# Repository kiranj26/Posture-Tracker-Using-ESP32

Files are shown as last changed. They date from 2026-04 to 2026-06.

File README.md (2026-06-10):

# Posture Tracker V2 — Product Grade Wearable

> **Branch:** `release/v2-product`  
> **Status:** In development  
> **V1 (MVP breadboard):** See [main branch](../../tree/main)

A product-grade evolution of the ESP32 posture tracker. V2 moves from a breadboard
prototype to a wearable device — custom PCB, LiPo battery, haptic motor, and a compact
shoulder-clip form factor small enough to wear all day.

**Hardware:** ESP32-S3-MINI-1 · MPU-6050 · DRV2605L + LRA · MAX98357A · 20mm speaker · 350mAh LiPo  
**Stack:** ESP-IDF 5.5.0 · PlatformIO · C only (no Arduino, no C++)  
**Target size:** 45×35×16mm (PCB + battery + clip)

---

## What's New in V2

| Feature | V1 | V2 |
|---|---|---|
| Alerts | Audio only | Haptic (early) + Audio (escalation) |
| MCU | ESP32 Dev Kit breakout | ESP32-S3-MINI-1 stamp module (built-in PCB antenna) |
| Power | USB only | 350mAh LiPo — 12–15 hr battery life |
| PCB | Breadboard + breakouts | Custom 2-layer PCB, all ICs direct |
| Speaker | 3W 4Ω (50mm, large) | 0.5W 8Ω (20mm, compact) |
| USB | Micro-USB | USB-C with proper CC resistors |
| Buttons | None | 2 buttons — recalibrate + snooze |
| Form factor | ~120×80mm breadboard | 45×35×16mm shoulder clip |

---

## Alert UX — Layered Haptic + Audio

The key design principle: **haptics for early alerts, audio only for escalation.**

| Time / State | Haptic | Audio |
|---|---|---|
| 10° for 3s — WARNING entry | Single tap | Silent |
| WARNING sustained | Double tap | Silent |
| 20° for 5s — BAD entry | Strong double tap | Double beep |
| BAD +8s | Triple pulse | Double beep |
| BAD +16s | Triple pulse | Double beep |
| BAD +24s onwards | Triple pulse | "Sit up straight" — repeats every 8s |
| Posture corrected | Long reward pulse | "Thank you good work" |
| 30s good streak | Gentle pulse | Silent |

SW2 (snooze button) mutes all audio for 10 minutes while haptics continue —
for meetings, calls, or quiet environments.

---

## Hardware

### Component List

| Component | Part | Purpose |
|---|---|---|
| ESP32-S3-MINI-1 | Espressif | MCU — dual core, BLE 5.0, native USB, built-in PCB antenna |
| MPU-6050 | InvenSense | 6-axis IMU — pitch/roll angle sensing |
| DRV2605L | Texas Instruments | Haptic driver — 123 built-in LRA waveforms |
| Z10SC2B LRA | Jinlong | 10mm linear resonant actuator — sharp haptic taps |
| MAX98357A | Maxim | I2S Class D amplifier — voice clips + tones |
| CMS-2009-SMT-TR | CUI Devices | 20mm 8Ω 0.5W speaker |
| MCP73831 | Microchip | LiPo charging IC — 100mA from USB-C |
| AP2112K-3.3 | Diodes Inc | 600mA LDO regulator — 3.3V rail |
| USBLC6-2SC6 | STMicro | USB ESD protection on D+/D- lines |
| 350mAh LiPo | Generic | Battery — 12–15 hour runtime |
| USB-C (HRO TYPE-C-31-M-12) | HRO | Charging + programming port, both-orientation USB 2.0 |

### Pin Assignment

| Signal | GPIO | Notes |
|---|---|---|
| I2C SDA | 8 | MPU-6050 + DRV2605L shared (GPIO21/22 do not exist on ESP32-S3) |
| I2C SCL | 9 | MPU-6050 + DRV2605L shared |
| I2S BCLK | 26 | MAX98357A |
| I2S WS | 25 | MAX98357A |
| I2S DOUT | 27 | MAX98357A |
| SW1 BOOT/CAL | 0 | Recalibrate / ESP32 boot |
| SW2 SNOOZE | 35 | 10-min snooze / mute toggle |
| SW3 RESET | EN pin | Hardware reset button |
| VBAT SENSE | 34 | ADC — battery voltage monitor |
| AUDIO MUTE | 48 | MAX98357A SD_MODE |
| USB D+ | 20 | Via USBLC6-2SC6 ESD protection |
| USB D- | 19 | Via USBLC6-2SC6 ESD protection |

---

## Architecture

### Three FreeRTOS tasks (V1) + Two new tasks (V2)

| Task | Core | Priority | Purpose |
|---|---|---|---|
| task_read_imu | 0 | 5 | IMU read every 100ms with light sleep |
| task_posture_fsm | 0 | 4 | State machine — unchanged from V1 |
| task_audio | 1 | 3 | Audio + haptic dispatch |
| task_buttons | 0 | 2 | Debounced button events |
| task_power | 0 | 1 | Battery monitor every 60s |

### New modules vs V1

```
NEW:      haptic.c    — DRV2605L I2C driver, waveform playback (non-blocking)
NEW:      power.c     — battery ADC, low-battery warning, deep sleep entry
NEW:      buttons.c   — debounced GPIO, short/long press detection

UNCHANGED: mpu6050.c  — I2C driver, atan2 angle math, EMA filter
UNCHANGED: posture_fsm.c — state machine logic (only alert commands change)
MODIFIED:  audio.c    — adds haptic command dispatch alongside audio
MODIFIED:  main.c     — init order adds haptic, power, buttons
```

---

## Power System

```
USB-C (5V) → Polyfuse → MCP73831 LiPo charger → 350mAh LiPo
                                                        ↓
                                                  AP2112K LDO
                                                        ↓
                                                    3.3V rail → all ICs
```

**Battery life estimate:**
- Active draw (IMU reading, no alerts): ~6mA average with light sleep
- 350mAh ÷ 6mA = ~58 hours theoretical
- Real world (audio bursts, haptic, occasional BLE): **12–15 hours**

**Low battery handling:**
- < 3.5V → warning beep + haptic
- < 3.3V → shutdown tone + deep sleep

---

## Form Factor

```
Assembled dimensions:
  PCB alone:        45 × 35 × 1.6mm
  PCB + battery:    45 × 35 × 8mm
  With clip:        45 × 38 × 16mm   ← final wearable size

Comparable to a car key fob.
Clips onto shirt collar, bra strap, or epaulette.
LRA motor faces the body for best haptic transmission.
Speaker grille faces outward.
USB-C and buttons accessible on edges.
```

---

## Development Phases

| Phase | Description | Status | Hardware |
|---|---|---|---|
| 7 | Haptic validation on breadboard (DRV2605L + LRA) | ⏳ Next | 📦 Parts ordered |
| 8 | Speaker swap validation (20mm 8Ω 1W) | ⏳ Next | 📦 Parts ordered |
| 9 | Battery system validation (MCP73831 + LiPo) | ⏳ Pending | 📦 Parts ordered |
| 10 | PCB V2 schematic + layout + fabrication (JLCPCB) | 🔄 PCB complete — awaiting order | Schematic ✅ ERC clean. Layout ✅ fully routed. DRC ✅ 0 errors, 0 unconnected, 2 cosmetic silk warnings. Gerbers ✅ `hardware/pcb/v2/`. JLCPCB order ⏳ pending. |
| 11 | Full integration + enclosure (3D printed clip) | ⏳ Pending | 🛒 Order after Phase 10 |

---

## Branch Structure

```
main                        ← V1 MVP (public, breadboard, complete)
  └── release/v2-product    ← this branch — all V2 work
        └── feature/haptics
        └── feature/speaker-swap
        └── feature/power-system
        └── feature/pcb-v2
        └── feature/enclosure
```

---

## PCB Layout — Complete

### Design decisions locked
- **2-layer board** — F.Cu for all signal and power traces, B.Cu solid GND copper pour
- **Trace widths (IPC-2221 verified, 1oz copper, 10°C rise)** — VBUS/VBUS_FUSED: 0.4mm, +3V3/VBAT/audio/motor: 0.3mm, all signals: 0.2mm
- **Net classes** — HighCurrent (0.4mm), Power (0.3mm), Audio (0.3mm), Motor (0.3mm), USB_Diff (0.2mm impedance-controlled), Default (0.2mm)
- **Via spec** — 0.8mm outer / 0.4mm drill (JLCPCB standard rule compliant)
- **Board size** — ~47.6 × 28.3mm (fits 45×35×16mm wearable form factor with battery)
- **Connectors** — J1: USB-C (HRO TYPE-C-31-M-12), J2: JST PH 2mm (battery), J3: Molex PicoBlade 53261-0271 (LRA haptic), LS1: Molex PicoBlade 53261-0271 (speaker)

### Routing status
| Net group | Connections | Status |
|---|---|---|
| GND | ~72 | ✅ B.Cu + F.Cu copper pour, stitching vias placed |
| +3V3 | 23 | ✅ Routed |
| VBAT | 7 | ✅ Routed |
| VBUS / VBUS_FUSED | 4 | ✅ Routed |
| I2C (SDA/SCL) | 6 | ✅ Routed |
| USB_DP / USB_DM | 8 | ✅ Routed |
| I2S (BCLK/WS/DOUT) | 3 | ✅ Routed |
| Signals + buttons | ~31 | ✅ Routed |

**Final DRC (2026-06-09):** 0 errors, 0 unconnected, 2 cosmetic silk warnings (U1 silkscreen clips board edge — JLCPCB trims automatically).

### File locations
```
hardware/
├── kicad/posture_tracker_v2/
│   └── posture_tracker_v2/    ← KiCad source (schematic + PCB + project files)
│       └── reports/           ← DRC.rpt, ERC.rpt
├── schematics/                ← Exported schematic PDF (posture_tracker_v2_v2.pdf)
├── pcb/
│   └── v2/
│       ├── gerbers/           ← 12 Gerber + drill files (canonical fab outputs)
│       └── posture_tracker_v2_gerbers.zip  ← upload this to JLCPCB
├── bom/                       ← Bill of materials
└── datasheets/                ← Component datasheets
```

---

## Hardware Visuals

### PCB — 3D View
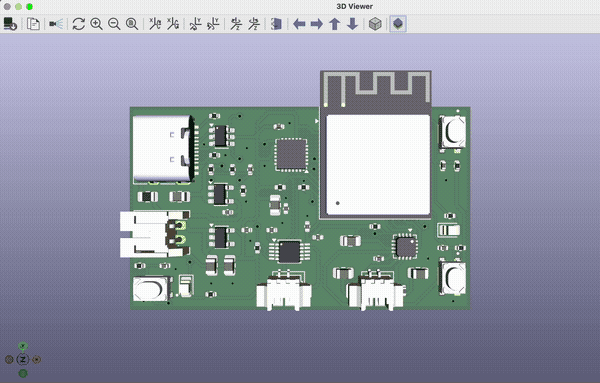
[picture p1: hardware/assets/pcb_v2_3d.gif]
PCB V2 3D view


### PCB — Top Layer
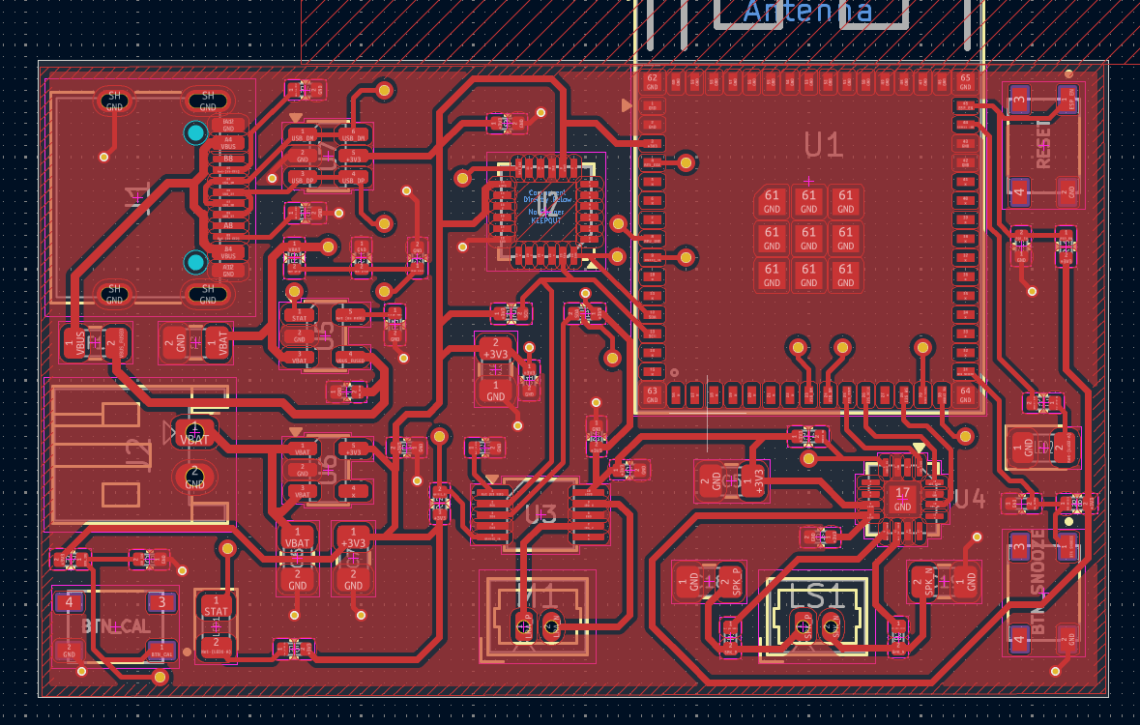
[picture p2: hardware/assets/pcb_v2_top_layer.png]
PCB V2 top layer


### PCB — Bottom Layer
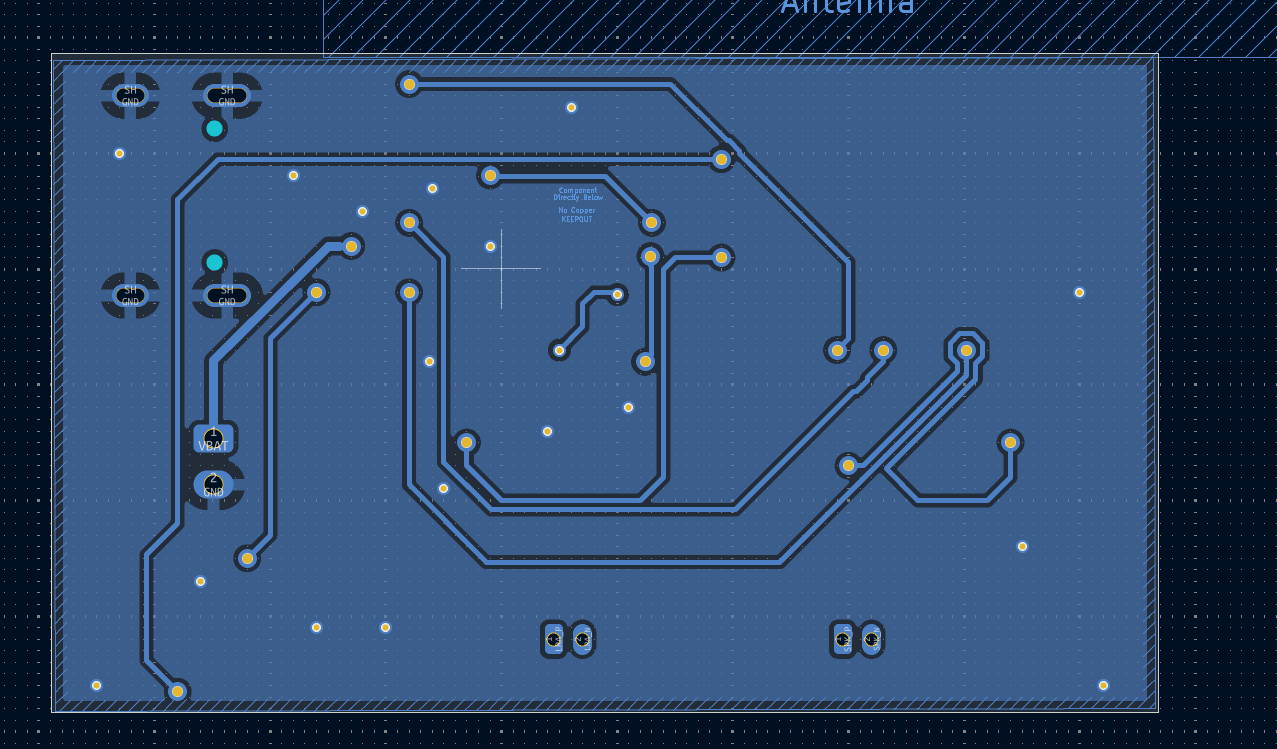
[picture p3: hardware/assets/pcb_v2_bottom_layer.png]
PCB V2 bottom layer


### PCB — Combined
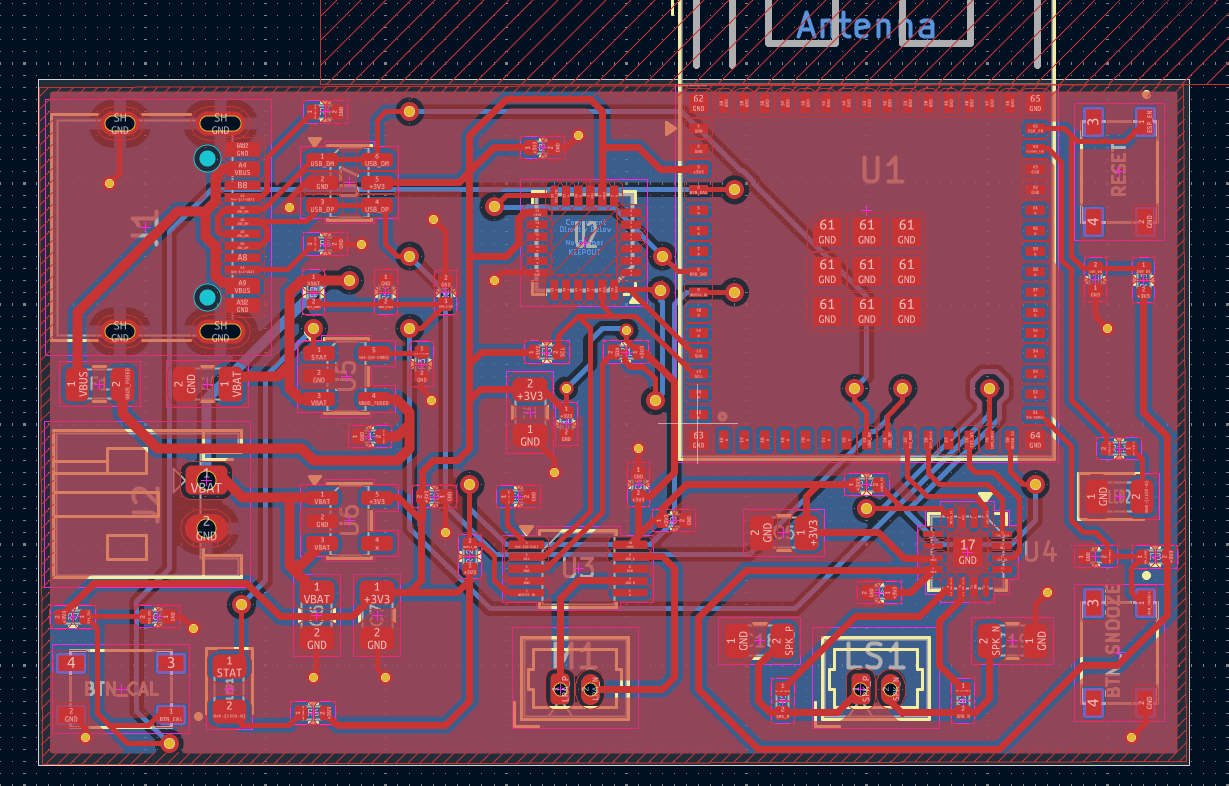
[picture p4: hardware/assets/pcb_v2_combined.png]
PCB V2 combined


### Schematic
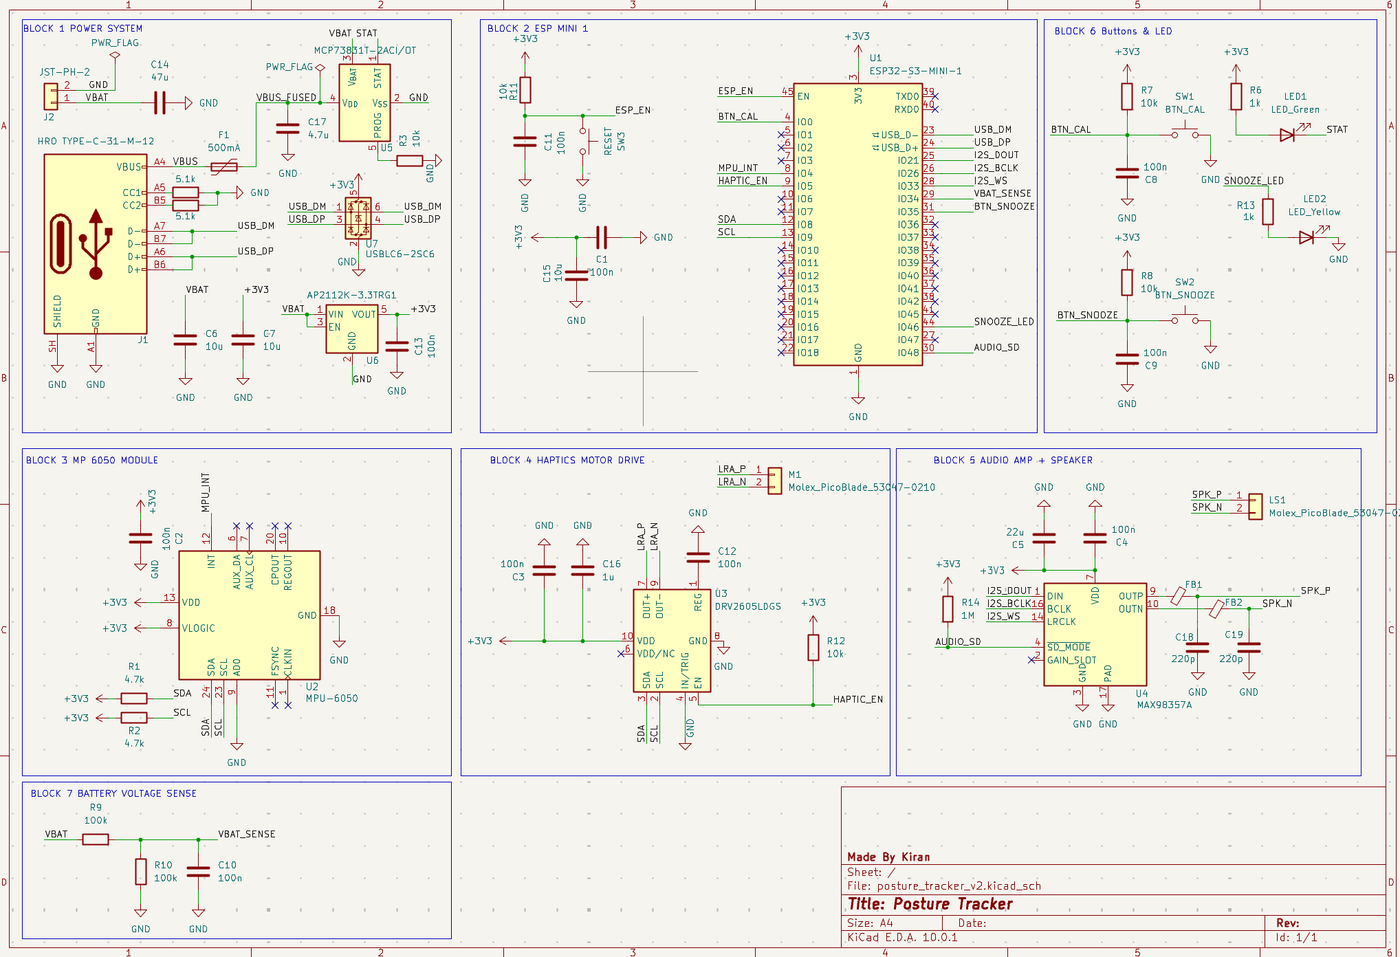
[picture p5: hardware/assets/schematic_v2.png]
V2 Schematic


> Full schematic PDF: [hardware/schematics/posture_tracker_v2_v2.pdf](hardware/schematics/posture_tracker_v2_v2.pdf)

> PCB layer PDFs (vector): [Top](hardware/assets/pcb_v2_top_layer.pdf) · [Bottom](hardware/assets/pcb_v2_bottom_layer.pdf) · [Combined](hardware/assets/pcb_v2_combined.pdf)

---

## Reference Docs

- [CLAUDE.md](CLAUDE.md) — full V2 architecture, component decisions, hard rules, PCB design reference
- [PHASES.md](PHASES.md) — V2 phase build guide (phases 7–11)
- [hardware/schematics/SCHEMATIC_GUIDE.md](hardware/schematics/SCHEMATIC_GUIDE.md) — full reasoning for every schematic block

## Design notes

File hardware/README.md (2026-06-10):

# Hardware

All hardware design files for Posture Tracker V2.

## Folder Structure

```
hardware/
├── datasheets/    ← PDF datasheets for every component on the BOM
├── kicad/         ← KiCad project files (schematic + PCB)
├── schematics/    ← Exported schematic PDFs per revision
├── pcb/           ← KiCad PCB layout + Gerber exports for JLCPCB
├── enclosure/     ← 3D printable clip files (STL + source)
└── bom/           ← Master BOM and JLCPCB-formatted exports
```

## Current Status

| Folder | Status | Notes |
|---|---|---|
| datasheets | ✅ Done | All component datasheets present — see datasheets/README.md |
| kicad | ✅ Complete | Schematic (ERC clean) + PCB layout (DRC clean) + Gerbers exported |
| schematics | ✅ Done | Exported PDF at `schematics/posture_tracker_v2_v2.pdf` |
| pcb | ✅ Gerbers ready | `pcb/v2/gerbers/` — 12 files + ZIP ready for JLCPCB upload |
| enclosure | ⬜ Not started | Waiting on PCB prototypes received (Phase 10) |
| bom | ✅ Master BOM started | Update as parts ordered for Phase 10 |

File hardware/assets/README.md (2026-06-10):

# Hardware Assets

Screenshots and renders for use in README files.

## How to capture these from KiCad

### PCB 3D render (`pcb_v2_3d.png`)
1. Open `hardware/kicad/posture_tracker_v2/posture_tracker_v2/posture_tracker_v2.kicad_pcb`
2. View → 3D Viewer
3. Rotate to a good angle (isometric top-left works well)
4. Screenshot → save as `hardware/assets/pcb_v2_3d.png`

### PCB top view (`pcb_v2_top.png`)
1. In the PCB Editor, press `Home` to fit board in view
2. Ensure F.Cu, F.Silkscreen, F.Mask, Edge.Cuts layers are visible
3. Screenshot → save as `hardware/assets/pcb_v2_top.png`

### Schematic (`schematic_v2.png`)
1. Open `posture_tracker_v2.kicad_sch` in KiCad Schematic Editor
2. File → Export → Export as Image
3. Format: PNG, resolution: 150 dpi
4. Save as `hardware/assets/schematic_v2.png`

## Files

| File | Status | Used in |
|---|---|---|
| `pcb_v2_3d.png` | ✅ Captured | `README.md` |
| `pcb_v2_top_layer.png` | ✅ Captured | `README.md` |
| `pcb_v2_bottom_layer.png` | ✅ Captured | `README.md` |
| `pcb_v2_combined.png` | ✅ Captured | `README.md` |
| `schematic_v2.png` | ✅ Captured | `README.md` |
| `pcb_v2_top_layer.pdf` | ✅ Generated via kicad-cli | `README.md` (inline link) |
| `pcb_v2_bottom_layer.pdf` | ✅ Generated via kicad-cli | `README.md` (inline link) |
| `pcb_v2_combined.pdf` | ✅ Generated via kicad-cli | `README.md` (inline link) |

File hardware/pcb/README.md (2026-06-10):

# PCB Fabrication Outputs

This folder contains the fabrication outputs sent to JLCPCB — not the KiCad source files.
KiCad source files live in `hardware/kicad/posture_tracker_v2/`.

## Folder structure

```
hardware/pcb/
└── v2/
    ├── gerbers/                          ← individual Gerber + drill files
    │   ├── posture_tracker_v2-F_Cu.gtl  ← top copper
    │   ├── posture_tracker_v2-B_Cu.gbl  ← bottom copper
    │   ├── posture_tracker_v2-F_Mask.gts
    │   ├── posture_tracker_v2-B_Mask.gbs
    │   ├── posture_tracker_v2-F_Paste.gtp
    │   ├── posture_tracker_v2-B_Paste.gbp
    │   ├── posture_tracker_v2-F_Silkscreen.gto
    │   ├── posture_tracker_v2-B_Silkscreen.gbo
    │   ├── posture_tracker_v2-Edge_Cuts.gm1
    │   ├── posture_tracker_v2-F_Courtyard.gbr
    │   ├── posture_tracker_v2-PTH.drl   ← plated through-holes
    │   └── posture_tracker_v2-NPTH.drl  ← non-plated holes (mounting)
    └── posture_tracker_v2_gerbers.zip   ← upload this to JLCPCB
```

## Board specs (V2)

| Spec | Value |
|---|---|
| Dimensions | ~47.6 × 28.3 mm |
| Layers | 2 |
| Thickness | 1.6mm |
| Copper weight | 1oz |
| Min trace width | 0.2mm signal / 0.3mm power / 0.4mm high-current |
| Surface finish | HASL (lead-free) or ENIG |
| Manufacturer | JLCPCB |
| Prototype qty | 5 units |

## DRC status (2026-06-09)

| Check | Result |
|---|---|
| DRC errors | 0 |
| Unconnected nets | 0 |
| Silk warnings | 2 (U1 silkscreen clips board edge — cosmetic, JLCPCB trims automatically) |
| Footprint errors | 0 |

## How to re-export Gerbers

1. Open `hardware/kicad/posture_tracker_v2/posture_tracker_v2/posture_tracker_v2.kicad_pcb` in KiCad
2. File → Plot → Format: Gerber, Output: `gerbers/`
3. Check: Use Protel filename extensions, uncheck: X2 format, Include netlist attributes
4. Click Plot, then Generate Drill Files
5. Copy outputs to `hardware/pcb/v2/gerbers/` and re-zip

## JLCPCB order checklist

- [x] Gerbers generated and verified
- [x] DRC clean — 0 errors, 0 unconnected
- [x] ZIP ready: `posture_tracker_v2_gerbers.zip`
- [ ] Upload to jlcpcb.com and confirm auto-detection (2 layers, correct dimensions)
- [ ] Order 5 prototype units
- [ ] Generate BOM + CPL for SMT assembly (optional)

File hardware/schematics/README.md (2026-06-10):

# Schematics

KiCad schematic files live here. One schematic per design revision.

## File naming convention

```
posture_tracker_v2_r1.kicad_sch    ← first revision
posture_tracker_v2_r2.kicad_sch    ← after first revision corrections
```

## Status

| File | Revision | Status | Notes |
|---|---|---|---|
| posture_tracker_v2_v2.pdf | R1 | ✅ Complete | Exported schematic PDF. All 7 blocks done. ERC: 0 errors, 5 warnings. Reddit review fixes applied. |

## Connector decisions (2026-05-03)

| Ref | Net | Connector | Reason |
|---|---|---|---|
| J1 | USB-C | HRO TYPE-C-31-M-12 | Dual-orientation USB 2.0 charging + programming |
| J2 | VBAT | JST PH 2mm horizontal | Battery connector standard |
| J3 | LRA_P / LRA_N | JST GH 1.25mm vertical | Matches Vybronics LRA motor cable |
| LS1 | SPK_P / SPK_N | JST GH 1.25mm vertical | Matches MECCANIXITY 20mm speaker 1.25mm cable |

## Schematic blocks progress

| Block | Description | Status |
|---|---|---|
| 1 | Power — USB-C (HRO TYPE-C-31-M-12), MCP73831, AP2112K, LiPo connector | ✅ Done |
| 2 | MCU — ESP32-S3-MINI-1, bypass caps (C1+C15), GPIO assignments | ✅ Done |
| 3 | IMU — MPU-6050, I2C pull-ups | ✅ Done |
| 4 | Haptic — DRV2605L, LRA connector, C16 VDD bulk | ✅ Done |
| 5 | Audio — MAX98357A, speaker connector | ✅ Done |
| 6 | Buttons (SW1/SW2/SW3) + LED1 + LED2 + ESD protection (U7) | ✅ Done |
| 7 | Battery voltage sense | ✅ Done |

## Post-schematic fixes applied (2026-05-03)

- USB-C B6/B7 cross-connection added (both cable orientations now work)
- C17 (4.7µF) added on VBUS_FUSED — MCP73831 VDD decoupling
- U1 footprint corrected from ESP32-S2-MINI-1 to ESP32-S3-MINI-1
- Total components: 46 (42 ICs + passives + 4 added via critique/review)

## KiCad project location

Active KiCad files are in `hardware/kicad/posture_tracker_v2/`.
See `hardware/kicad/KICAD_CONTEXT.md` for full design context and session log.
See `hardware/kicad/KICAD_BEGINNER_GUIDE.md` for step-by-step drawing instructions.

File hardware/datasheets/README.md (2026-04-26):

# Datasheets

Drop all component datasheets here as PDFs. One file per component.

## Required — download and place here before starting schematic

| Component | Filename | Status |
|---|---|---|
| ESP32-S3-MINI-1U | esp32-s3-mini-1_mini-1u_datasheet_en.pdf | ✅ Downloaded |
| MPU-6050 | mpu6050_datasheet.pdf | ⬜ Still needed |
| DRV2605L | drv2605l.pdf | ✅ Downloaded |
| MAX98357A | MAX98357A-MAX98357B.pdf | ✅ Downloaded |
| MCP73831 | MCP73831.pdf | ✅ Downloaded |
| AP2112K-3.3 | ap2112k_datasheet.pdf | ⬜ Still needed |
| Vybronics VG1030001XH | vg1030001xh_datasheet.pdf | ⬜ Still needed |
| GCT USB4135-GF-A | usb4135_datasheet.pdf | ⬜ Still needed |
| Alps SKRPABE010 | skrpabe010_datasheet.pdf | ⬜ Still needed |

## Where to download

- ESP32-S3-MINI-1U: espressif.com/en/support/documents/technical-documents
- MPU-6050: invensense.tdk.com
- DRV2605L: ti.com/product/DRV2605L
- MAX98357A: analog.com/en/products/max98357a
- MCP73831: microchip.com/en-us/product/mcp73831
- AP2112K: diodes.com/products/detail/ap2112k-3-3trg1
- VG1030001XH: vybronics.com
- USB4135: gct.co
- SKRPABE010: alps.com

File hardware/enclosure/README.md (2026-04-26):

# Enclosure

3D printable enclosure files live here. Designed for shoulder clip mounting.

## File naming convention

```
clip_v1.step           ← STEP file (universal, import into any CAD tool)
clip_v1.stl            ← STL for slicing and printing
clip_v1.f3d            ← Fusion 360 source (if designed in Fusion 360)
```

## Target dimensions

```
PCB pocket:     47 × 37 × 9mm  (1mm clearance each side of PCB)
Battery slot:   37 × 27 × 6mm  (behind PCB pocket)
Overall:        45 × 38 × 16mm
Clip opening:   15mm max gap
Material:       PETG
```

## Design requirements checklist

- [ ] PCB slides in without screws (friction fit)
- [ ] USB-C port accessible from bottom edge
- [ ] Both buttons accessible on front face
- [ ] Speaker grille on top face (5-8 holes, 1mm dia)
- [ ] LRA motor recess on back face (contacts body)
- [ ] Spring clip mechanism fits 5-15mm fabric thickness
- [ ] No sharp edges

## Status

| File | Version | Status |
|---|---|---|
| clip_v1 | V1 | ⬜ Not started — waiting for PCB V2 dimensions confirmed |

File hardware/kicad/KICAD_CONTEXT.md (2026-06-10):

# KICAD_CONTEXT.md — PCB & Schematic Design Context

> **Branch:** `feature/pcb-schematic`
> **Purpose:** This file is the living context document for all KiCad schematic
> and PCB design work. Update this file every session — what was done, what decisions
> were made, what is left. Future Claude sessions must read this file first before
> giving any PCB or schematic advice.
> **KiCad version:** 8.x (download from kicad.org)

---

## Current Status

| Stage | Status | Notes |
|---|---|---|
| KiCad installed | ✅ Done | |
| Project created | ✅ Done | posture_tracker_v2.kicad_sch |
| Power block schematic | ✅ Done | ERC clean, 0 errors |
| MCU block schematic | ✅ Done | ERC clean, 0 errors |
| IMU block schematic | ✅ Done | ERC clean, 0 errors |
| Haptic block schematic | ✅ Done | ERC clean, 0 errors |
| Audio block schematic | ✅ Done | ERC clean, 0 errors |
| Buttons + LED schematic | ✅ Done | ERC clean, 0 errors |
| Battery sense schematic | ✅ Done | ERC clean, 0 errors |
| Full schematic DRC | ✅ Done | 0 errors, 5 warnings (all acceptable) |
| Schematic critique fixes | ✅ Done | SW3 reset, MPU_INT, HAPTIC_EN+R12, SKRPABE010 buttons, LED2+R13 snooze, C14 VBAT bulk, antenna note |
| Reddit review fixes | ✅ Done | USB-C B6/B7 cross-connection, C17 VBUS_FUSED bypass cap, U7 ESD protection, C15/C16 decoupling, U1 footprint fixed to ESP32-S3-MINI-1 |
| PCB layout started | ✅ Done | 57 components placed |
| PCB layout complete | ✅ Done | All nets routed — see routing log below |
| PCB DRC clean | ✅ Done | 0 errors, 0 unconnected, 2 cosmetic silk warnings (2026-06-09) |
| Gerbers exported | ✅ Done | `hardware/pcb/v2/gerbers/` — 10 Gerbers + 2 drill files + ZIP |
| JLCPCB order placed | ⬜ Not started | ZIP ready at `hardware/pcb/v2/posture_tracker_v2_gerbers.zip` |

---

## Design Decisions Log

> Add an entry here every time a significant design decision is made.
> Include the date, what was decided, and why.

| Date | Decision | Reason |
|---|---|---|
| 2026-04-26 | ESP32-S3-MINI-1U chosen over ESP32 devkit | Smaller, native USB, BLE 5.0 |
| 2026-04-26 | 8Ω speaker instead of 4Ω | Lower power draw, MAX98357A supports both |
| 2026-04-26 | LRA motor: Vybronics VG1030001XH | Active part, wire leads, 1.5G force |
| 2026-04-26 | MCP73831 charge current: 100mA | Conservative, protects 350mAh cell |
| 2026-04-26 | AP2112K-3.3 LDO | 600mA headroom, covers audio peak current |
| 2026-04-26 | Board size target: 45×35mm | Fits enclosure clip, smaller than credit card |
| 2026-05-03 | Changed U1 to ESP32-S3-MINI-1 (not MINI-1U) | MINI-1 has built-in PCB antenna, 65 pads; MINI-1U needs external antenna. Both use same pin assignments |
| 2026-05-03 | Changed J1 to HRO TYPE-C-31-M-12 | Better KiCad library support, correct 14-pin mid-mount footprint for 2-layer PCB |
| 2026-05-03 | Added U7 USBLC6-2SC6 ESD protection on USB D+/D- | Protects ESP32-S3 USB PHY from ESD events on connector; essential for wearable handling |
| 2026-05-03 | Added C15 (10µF, 0805) on ESP32-S3 VDD33 | Bulk decoupling for MCU power rail; reduces voltage sag during Bluetooth bursts |
| 2026-05-03 | Added C16 (1µF, 0402) on DRV2605L VDD | Datasheet recommended local bypass; original design only had 100nF |
| 2026-05-03 | Added C17 (4.7µF, 0402) on VBUS_FUSED | MCP73831 VDD decoupling — was missing. Reviewer flagged; 4.7µF per MCP73831 datasheet recommendation |
| 2026-05-03 | USB-C B6/B7 cross-connection per USB-IF spec | Per spec Table 3-1: A6+B7=D+, A7+B6=D- (diagonal). Both cable orientations now work |
| 2026-06-09 | Trace widths set per IPC-2221 (1oz copper, external layer, 10°C rise) | 0.2mm=745mA, 0.3mm=999mA, 0.4mm=1231mA. VBUS=0.4mm (500mA USB), +3V3=0.3mm, SPK/LRA=0.3mm (~500mA peak), signals=0.2mm |
| 2026-06-09 | LS1 and M1 switched to Molex PicoBlade 53261-0271 (horizontal, 2-pin) | Better cable orientation for wearable form factor. JST GH replaced with PicoBlade for both speaker and LRA motor connectors |
| 2026-06-09 | GND strategy: F.Cu fill (solid connection) + B.Cu fill + stitching vias | Solid pad connection chosen over thermal relief — correct for reflow-soldered SMD. Thermal relief is only needed for hand-soldered through-hole. Stitching vias placed to connect F.Cu copper islands to B.Cu plane |
| 2026-06-09 | Via spec: 0.8mm outer / 0.4mm drill across all vias | JLCPCB standard design rule minimum. Applied uniformly to all 19 vias in design |

---

## Schematic Blocks — What to Draw

The schematic is split into 7 logical blocks. Draw one block at a time,
verify it, then move to the next. Do not mix blocks.

### Block 1 — Power System (draw first)
```
USB-C (J1)
  → CC1 pin: 5.1kΩ to GND
  → CC2 pin: 5.1kΩ to GND
  → VBUS: → Polyfuse F1 (500mA) → MCP73831 VIN

MCP73831 (U5)
  → VDD: 3.3V (from LDO)
  → VBAT: → JST-PH J2 pin 1 (battery +)
  → GND: → JST-PH J2 pin 2 (battery -)
  → PROG: → 10kΩ R3 → GND  (sets 100mA charge current)
  → STAT: → 1kΩ R6 → LED1 → 3.3V

AP2112K-3.3 (U6)
  → VIN: LiPo+ (from JST J2 pin 1)
  → EN: tie to VIN (always on)
  → GND: GND
  → VOUT: 3.3V rail
  → C_in: 10µF to GND (close to VIN pin)
  → C_out: 10µF to GND (close to VOUT pin)

Power flags:
  Add PWR_FLAG on 3.3V net and GND net (stops ERC errors)
```

### Block 2 — MCU (ESP32-S3-MINI-1)
```
ESP32-S3-MINI-1 (U1)
  → 3V3: 3.3V rail + 100nF bypass cap to GND
  → GND: GND
  → GPIO8:  SDA net (GPIO22 does not exist on ESP32-S3 — corrected)
  → GPIO9:  SCL net (GPIO22 does not exist on ESP32-S3 — corrected)
  → GPIO21: no-connect (unused)
  → GPIO25: I2S_WS net
  → GPIO26: I2S_BCLK net
  → GPIO27: I2S_DOUT net
  → GPIO0: BTN_CAL net (also BOOT pin)
  → GPIO35: BTN_SNOOZE net
  → GPIO34: VBAT_SENSE net
  → GPIO48: AUDIO_SD net
  → GPIO19: USB_DM net
  → GPIO20: USB_DP net
  → EN: 10kΩ pull-up to 3.3V + 100nF to GND (reset circuit)
  → All unused GPIO: leave unconnected (add no-connect marker)

Antenna keep-out note:
  Add a note on schematic: "3mm copper keep-out under antenna edge of U1"
```

### Block 3 — IMU (MPU-6050)
```
MPU-6050 (U2)
  → VCC: 3.3V + 100nF bypass cap to GND
  → GND: GND
  → SDA: SDA net (shared with DRV2605L)
  → SCL: SCL net (shared with DRV2605L)
  → AD0: GND (sets I2C address 0x68)
  → INT: test point only, no connection in V2
  → XDA, XCL, FSYNC: GND

I2C pull-ups (shared, place once in this block):
  → SDA net: 4.7kΩ R1 to 3.3V
  → SCL net: 4.7kΩ R2 to 3.3V
```

### Block 4 — Haptic (DRV2605L + LRA)
```
DRV2605L (U3)
  → VDD: 3.3V + 100nF bypass cap to GND
  → GND: GND
  → SDA: SDA net (shared with MPU-6050)
  → SCL: SCL net (shared with MPU-6050)
  → EN: 3.3V (always enabled)
  → IN/TRIG: GND (using I2C mode, not GPIO trigger)
  → LRA+: LRA motor pad 1
  → LRA-: LRA motor pad 2

LRA Motor (M1):
  → 2-pin connector or spring pads
  → No polarity (LRA is AC driven)
```

### Block 5 — Audio (MAX98357A + Speaker)
```
MAX98357A (U4)
  → PVDD: 3.3V + 22µF bulk cap + 100nF bypass cap to GND
  → DVDD: 3.3V + 100nF bypass cap to GND
  → GND: GND
  → BCLK: I2S_BCLK net
  → LRCLK: I2S_WS net
  → DIN: I2S_DOUT net
  → SD_MODE: AUDIO_SD net (GPIO48) — pull HIGH = on, pull LOW = off
  → GAIN: floating (9dB default)
  → OUT+: speaker pad 1
  → OUT-: speaker pad 2

Speaker (LS1):
  → 2-pin connector, 8Ω
```

### Block 6 — Buttons + LED
```
SW1 — BOOT/CAL button
  → One side: GND
  → Other side: BTN_CAL net → 10kΩ R7 pull-up to 3.3V
                            → 100nF C_debounce to GND
                            → GPIO0 (BOOT pin on ESP32-S3)

SW2 — SNOOZE button
  → One side: GND
  → Other side: BTN_SNOOZE net → 10kΩ R8 pull-up to 3.3V
                               → 100nF C_debounce to GND
                               → GPIO35

LED1 — Charge indicator
  → Anode: 3.3V via 1kΩ R6
  → Cathode: STAT pin of MCP73831
  (Already in Block 1 — just note it here)
```

### Block 7 — Battery Voltage Sense
```
Voltage divider on LiPo+ rail:
  LiPo+ → 100kΩ R9 → VBAT_SENSE net → GPIO34 (ADC1 CH6)
  VBAT_SENSE net → 100kΩ R10 → GND

  ADC reads 0–3.3V → multiply by 2 in firmware = actual LiPo voltage
  Add 100nF cap on VBAT_SENSE to GND for noise filtering
```

---

## Net Names (use exactly these in KiCad)

| Net name | Description |
|---|---|
| `+3V3` | 3.3V regulated rail |
| `VBAT` | LiPo battery voltage (3.0–4.2V) |
| `VBUS` | USB 5V input |
| `GND` | Ground |
| `SDA` | I2C data — shared MPU-6050 + DRV2605L |
| `SCL` | I2C clock — shared MPU-6050 + DRV2605L |
| `I2S_BCLK` | I2S bit clock to MAX98357A |
| `I2S_WS` | I2S word select to MAX98357A |
| `I2S_DOUT` | I2S data out to MAX98357A |
| `AUDIO_SD` | MAX98357A SD_MODE — software mute |
| `BTN_CAL` | Calibrate button signal |
| `BTN_SNOOZE` | Snooze button signal |
| `VBAT_SENSE` | Voltage divider output to ADC |
| `USB_DP` | USB D+ to ESP32-S3 |
| `USB_DM` | USB D- to ESP32-S3 |

---

## Component Reference Designators

| Ref | Component |
|---|---|
| U1 | ESP32-S3-MINI-1 (built-in PCB antenna) |
| U2 | MPU-6050 |
| U3 | DRV2605L |
| U4 | MAX98357A |
| U5 | MCP73831 |
| U6 | AP2112K-3.3 |
| U7 | USBLC6-2SC6 — USB ESD protection (SOT-23-6) |
| M1 | LRA motor (VG1030001XH) |
| LS1 | Speaker (20mm 8Ω) |
| J1 | USB-C connector (HRO TYPE-C-31-M-12) |
| J2 | JST-PH battery connector |
| J3 | Debug/programming header (2-pin) |
| SW1 | Button — BOOT/CAL (Alps SKRPABE010) |
| SW2 | Button — SNOOZE (Alps SKRPABE010) |
| SW3 | Button — RESET (Alps SKRPABE010) |
| LED1 | Charge indicator (green) |
| LED2 | Snooze indicator |
| F1 | Polyfuse 500mA |
| R1 | 4.7kΩ — I2C SDA pull-up |
| R2 | 4.7kΩ — I2C SCL pull-up |
| R3 | 10kΩ — MCP73831 PROG (charge current) |
| R4 | 5.1kΩ — USB-C CC1 |
| R5 | 5.1kΩ — USB-C CC2 |
| R6 | 1kΩ — LED1 current limit |
| R7 | 10kΩ — SW1 pull-up |
| R8 | 10kΩ — SW2 pull-up |
| R9 | 100kΩ — VBAT sense divider top |
| R10 | 100kΩ — VBAT sense divider bottom |
| R11 | 10kΩ — ESP32 EN pull-up |
| R12 | 10kΩ — HAPTIC_EN pull-up |
| R13 | 1kΩ — LED2 current limit |
| C1 | 100nF — U1 VDD33 bypass |
| C2 | 100nF — U2 bypass |
| C3 | 100nF — U3 VDD bypass |
| C4 | 100nF — U4 DVDD bypass |
| C5 | 22µF — U4 PVDD bulk |
| C6 | 10µF — U6 LDO input bulk |
| C7 | 10µF — U6 LDO output bulk |
| C8 | 100nF — SW1 debounce |
| C9 | 100nF — SW2 debounce |
| C10 | 100nF — VBAT sense filter |
| C11 | 100nF — ESP32 EN filter |
| C12 | 100nF — U3 extra bypass |
| C13 | 100nF — SW3 debounce |
| C14 | 47µF — VBAT bulk cap |
| C15 | 10µF — U1 VDD33 bulk (0805) |
| C16 | 1µF — U3 VDD local bulk (0402) |
| C17 | 4.7µF — VBUS_FUSED bypass / U5 VDD decoupling (0402) |

---

## KiCad Libraries Needed

These symbols and footprints are not in KiCad's default library.
Must be downloaded or created manually.

| Component | Symbol source | Footprint source |
|---|---|---|
| ESP32-S3-MINI-1 | KiCad RF_Module lib | KiCad RF_Module:ESP32-S3-MINI-1 (65 pads) |
| MPU-6050 | KiCad default (Sensor lib) | KiCad default |
| DRV2605L | SnapEDA / KiCad official | TSSOP-10 3x3mm |
| MAX98357A | SnapEDA | TQFN-16-1EP 3x3mm |
| MCP73831 | KiCad default | KiCad default (SOT-23-5) |
| AP2112K | SnapEDA | SOT-23-5 (standard) |
| USBLC6-2SC6 | KiCad default | SOT-23-6 |
| HRO TYPE-C-31-M-12 | KiCad Connector lib | Connector_USB:USB_C_Receptacle_HRO_TYPE-C-31-M-12 |
| VG1030001XH | Create manually (2 pads) | Create manually |
| Alps SKRPABE010 | Custom / SnapEDA | SW_SKRPABE010 |

> SnapEDA (snapeda.com) — search by part number, download KiCad format.
> Always verify footprint pad dimensions against the component datasheet.

---

## Critical Design Rules (must not violate)

1. ESP32-S3 antenna area: 3mm copper keepout on PCB under antenna edge
2. USB-C CC pins: BOTH CC1 and CC2 need 5.1kΩ to GND — non-negotiable
3. I2C pull-ups: only ONE set (R1, R2) — do not add more
4. MAX98357A SD_MODE: must be driven, never floating
5. MCP73831 PROG: 10kΩ sets 100mA — do not change without recalculating
6. LiPo connector: JST-PH keyed, pin 1 = positive — verify before soldering
7. Bypass caps: place within 1mm of each IC VCC pin on same copper layer
8. Board outline: 45×35mm — check all components fit before routing

---

## Session Log

> Add an entry after every work session. One line per session.

| Date | What was done | What is next |
|---|---|---|
| 2026-04-26 | Branch created, folder structure set up, context file written | Install KiCad, create project, start Block 1 power schematic |
| 2026-04-27 | Block 1 (Power) schematic complete — J1, F1, U5, J2, U6, bypass caps, PWR_FLAG. ERC: 0 errors. | Draw Block 2 (MCU — ESP32-S3-MINI-1U) |
| 2026-05-02 | Blocks 2–7 complete — ESP32-S3, MPU-6050, DRV2605L, MAX98357A, Buttons+LED, VBAT sense. All 37 footprints assigned. Full ERC: 0 errors, 30 warnings. | Schematic critique fixes |
| 2026-05-02 | Schematic critique complete — added SW3 (RESET), MPU_INT net, HAPTIC_EN+R12 pull-up, SKRPABE010 button footprints, LED2+R13 snooze indicator, C14 47µF VBAT bulk cap, antenna keep-out note. 42 components, ERC: 0 errors, 30 warnings. | Start PCB layout |
| 2026-05-03 | Reddit review fixes: fixed USB-C B6/B7 cross-connection (A6+B7=D+, A7+B6=D- per USB-IF spec), added C17 4.7µF on VBUS_FUSED (MCP73831 VDD decoupling), confirmed U7 USBLC6-2SC6 ESD protection, added C15 (10µF U1 VDD33) and C16 (1µF U3 VDD). Fixed U1 footprint from ESP32-S2-MINI-1 → ESP32-S3-MINI-1 (critical — wrong pad count). Deleted premature Gerbers. ERC: 0 errors, 5 warnings. DRC: 4 cosmetic warnings, 148 unconnected pads (routing not done). | PCB routing |
| 2026-06-09 | PCB routing started. All signal, power, and USB nets routed on F.Cu. HAPTIC_EN and MPU_INT routed via vias through B.Cu. All components unlocked for placement. | Trace width verification |
| 2026-06-09 | Trace widths fixed to IPC-2221 standard across all 364 segments: VBUS/VBUS_FUSED → 0.4mm, +3V3/VBAT/audio/motor → 0.3mm, signals → 0.2mm. 19 vias updated to 0.8mm/0.4mm (JLCPCB spec). Net classes written to .kicad_pro: HighCurrent, Power, Audio, Motor, USB_Diff, Default. CLAUDE.md Section 18 added with full trace width reference table. | GND copper fill |
| 2026-06-09 | LS1 and M1 connectors switched to Molex PicoBlade 53261-0271 horizontal variant. B.Cu GND zone verified to cover full board. F.Cu GND zone added (solid pad connection). GND stitching vias placed across board to connect F.Cu islands to B.Cu plane. | DRC clean + Gerber export |
| 2026-06-09 | Final DRC: 0 errors, 0 unconnected, 2 cosmetic silk warnings (U1 silkscreen clips board edge — JLCPCB trims automatically). Gerbers exported to hardware/pcb/v2/gerbers/ (10 layers + PTH.drl + NPTH.drl). ZIP created: posture_tracker_v2_gerbers.zip. Folder structure reorganised: KiCad source stays in hardware/kicad/, canonical fab outputs in hardware/pcb/v2/. | JLCPCB order |

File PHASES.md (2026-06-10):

# PHASES.md — Posture Tracker V2 Build Guide

> **Branch:** `release/v2-product`
> This file documents every V2 development phase with entry conditions, exact steps,
> and pass criteria. No phase may be skipped. No PR merged to `release/v2-product`
> without the phase pass criteria verified on real hardware.
> V1 phases (0–6) are on the [main branch](../../tree/main).

---

## Hardware Procurement Log

All components confirmed and ordered as of 2026-04-26. Documented here so
future sessions know exactly what hardware is in hand and why each part was chosen.

### Ordered — In Transit

| Item | Source | Order Ref | Qty | Unit Cost | Phase | Status |
|---|---|---|---|---|---|---|
| Adafruit DRV2605L breakout #2305 | Adafruit | — | 1 | $7.95 | 7 | 🚚 In transit |
| MECCANIXITY 20mm 8Ω 1W speaker | Amazon | — | 4pk | $8.49 | 8 | 🚚 In transit |
| Vybronics VG1030001XH LRA motor | Digikey | 1670-VG1030001XH-ND | 3 | $2.96 | 7 | 🚚 In transit |
| Adafruit 350mAh LiPo #2750 | Digikey | 1528-1858-ND | 2 | $6.95 | 9 | 🚚 In transit |

### Component Selection Rationale

**Haptic Driver — Adafruit DRV2605L breakout #2305**
- Chosen because: breakout board handles all support components (pull-ups, caps)
- Shares existing I2C bus with MPU-6050 — no new GPIO pins
- I2C address 0x5A — no conflict with MPU-6050 at 0x68
- 123 built-in LRA waveform library — no waveform generation in firmware
- For Phase 7 breadboard only — bare DRV2605LDGSR IC goes on PCB V2

**LRA Motor — Vybronics VG1030001XH (Digikey 1670-VG1030001XH-ND)**
- 10mm diameter, LRA Z-axis — correct axis for wearable (vibrates into skin)
- 2VAC rated, 210Hz resonant frequency — DRV2605L auto-tracks resonance
- 1.5G vibration force — strong enough to feel through clothing
- **Wire leads pre-attached** — plugs directly into DRV2605L breakout, no soldering thin wire
- Active part, not discontinued — safe to design PCB V2 around
- Ordered qty 3: 1 for Phase 7 breadboard, 2 spares

**Speaker — MECCANIXITY 20mm 8Ω 1W (Amazon)**
- 20mm diameter — minimum size for intelligible voice clip playback
- 8Ω — matches MAX98357A V2 configuration (changed from 4Ω in V1)
- 1W — adequate for escalation alerts at 0.5–1 metre
- Pre-soldered 100mm wires — plug straight into MAX98357A output terminals
- 4 pack — 1 for Phase 8 testing, 3 spares / PCB V2 candidates
- Arrives Friday May 1 — Phase 8 can start immediately on arrival

**Battery — Adafruit #2750 350mAh LiPo (Digikey 1528-1858-ND)**
- 350mAh at 3.7V — gives 12–15 hour real-world runtime (calculated in CLAUDE.md §6)
- Dimensions 36×20×5.6mm — fits behind 45×35mm PCB with 1mm clearance each side
- JST-PH connector — matches MCP73831 charging circuit connector standard
- Built-in PCM protection circuit — prevents overcharge, overdischarge, short circuit
- Ordered qty 2: 1 for Phase 9 validation, 1 spare

### Still To Order (Phase 10 — after Phases 7–9 validated)

These are NOT ordered yet. Order only after Phase 7, 8, 9 pass criteria are confirmed
on breadboard. Ordering early risks buying parts that need to change.

| Item | Digikey Part # | Qty | Phase |
|---|---|---|---|
| ESP32-S3-MINI-1U-N8 | 1965-ESP32-S3-MINI-1U-N8CT-ND | 3 | 10 |
| MPU-6050 bare IC | 1428-1011-1-ND | 3 | 10 |
| DRV2605LDGSR bare IC | 296-43883-1-ND | 3 | 10 |
| MAX98357AEWL bare IC | MAX98357AEWL+CT-ND | 3 | 10 |
| MCP73831T-2ACI/OT | MCP73831T-2ACI/OTCT-ND | 3 | 10 |
| AP2112K-3.3TRG1 | AP2112K-3.3TRG1DICT-ND | 3 | 10 |
| GCT USB4135-GF-A USB-C | 2073-USB4135-GF-ACT-ND | 3 | 10 |
| Alps SKRPABE010 buttons | SKRPABE010CT-ND | 6 | 10 |
| JST-PH 2-pin connector | 455-1719-ND | 3 | 10 |
| 4.7kΩ 0402 resistor | 311-4.7KLRCT-ND | 50 | 10 |
| 10kΩ 0402 resistor | 311-10.0KLRCT-ND | 50 | 10 |
| 5.1kΩ 0402 resistor | 311-5.10KLRCT-ND | 50 | 10 |
| 1kΩ 0402 resistor | 311-1.00KLRCT-ND | 50 | 10 |
| 100nF 0402 cap | 311-1375-1-ND | 50 | 10 |
| 10µF 0805 cap | 399-8419-1-ND | 20 | 10 |
| 22µF 0805 cap | 399-8423-1-ND | 10 | 10 |
| 1µF 0402 cap | 311-1543-1-ND | 20 | 10 |
| 500mA polyfuse 0805 | MINISMDC050F/24-2CT-ND | 5 | 10 |
| Green LED 0402 | 160-1446-1-ND | 10 | 10 |

> **Before ordering Phase 10 parts:** verify every Digikey part number in browser.
> Part numbers above are correct at time of writing (2026-04-26) but may change.
> Always confirm description matches before adding to cart.

---

## Phase Map

```
Phase 7 ──► Phase 8 ──► Phase 9 ──► Phase 10 ──► Phase 11
Haptics     Speaker     Battery      PCB V2        Enclosure
breadboard  swap        system       fabrication   + full
validation  validation  validation                 integration

  ⏳ Next    📦 Parts    📦 Parts     🔄 Design     ⏳ Pending
             ordered     ordered
```

---

## Phase 7 — Haptic Validation on Breadboard

### Status: ⏳ Next

### Objective
Prove the DRV2605L + LRA motor combination works, feels right, and produces
clearly distinguishable feedback patterns — all before committing to PCB layout.
This phase has zero PCB risk. If something feels wrong, fix it in firmware.

### Entry conditions
- V1 breadboard (phases 0–6) working and flashed
- Adafruit DRV2605L breakout board purchased
- 10mm LRA motor purchased (Jinlong Z10SC2B or equivalent)
- `release/v2-product` branch checked out

### Hardware needed
| Item | Where to buy | Approx cost |
|---|---|---|
| Adafruit DRV2605L breakout (#2305) | adafruit.com | $7.95 |
| 10mm LRA motor | Digikey / Mouser / Adafruit #1201 | $3–5 |
| 4× jumper wires | Already have | — |

### Wiring — DRV2605L breakout to ESP32

```
DRV2605L breakout   →   ESP32
─────────────────────────────────
VIN                 →   3.3V
GND                 →   GND
SDA                 →   GPIO 21   (shared with MPU-6050)
SCL                 →   GPIO 22   (shared with MPU-6050)
LRA+ / MOTOR+       →   LRA motor wire 1
LRA- / MOTOR-       →   LRA motor wire 2
```

> The Adafruit breakout has onboard pull-ups on SDA/SCL. The MPU-6050 GY-521 breakout
> also has onboard pull-ups. With both on the same bus you now have two sets of pull-ups
> in parallel — effective pull-up ~2.35kΩ. This is within I2C spec. Do NOT add more.

> LRA motor has no polarity. Either wire order works.

### What to build

**New file: `src/main/haptic.c`**
```c
#include "config.h"
#include "esp_log.h"
#include "driver/i2c.h"
#include "haptic.h"

static const char *TAG = "HAPTIC";

static esp_err_t drv_write(uint8_t reg, uint8_t val)
{
    i2c_cmd_handle_t cmd = i2c_cmd_link_create();
    i2c_master_start(cmd);
    i2c_master_write_byte(cmd, (DRV2605L_ADDR << 1) | I2C_MASTER_WRITE, true);
    i2c_master_write_byte(cmd, reg, true);
    i2c_master_write_byte(cmd, val, true);
    i2c_master_stop(cmd);
    esp_err_t ret = i2c_master_cmd_begin(I2C_MASTER_PORT, cmd, pdMS_TO_TICKS(I2C_TIMEOUT_MS));
    i2c_cmd_link_delete(cmd);
    return ret;
}

esp_err_t haptic_init(void)
{
    // Exit standby, internal trigger mode
    if (drv_write(0x01, 0x00) != ESP_OK) {
        ESP_LOGE(TAG, "DRV2605L not found on I2C bus at 0x%02X", DRV2605L_ADDR);
        return ESP_FAIL;
    }
    drv_write(0x1D, 0xA8);  // LRA open-loop
    drv_write(0x03, 0x02);  // LRA library
    drv_write(0x16, 0x53);  // Rated voltage ~1.8Vrms for 10mm LRA
    drv_write(0x17, 0x74);  // Overdrive clamp voltage
    ESP_LOGI(TAG, "DRV2605L initialised — LRA mode");
    return ESP_OK;
}

void haptic_play(uint8_t waveform_id)
{
    drv_write(0x04, waveform_id);  // Waveform slot 0
    drv_write(0x05, 0x00);          // End of sequence
    drv_write(0x0C, 0x01);          // GO
}
```

**New file: `src/main/haptic.h`**
```c
#pragma once
#include "esp_err.h"
#include <stdint.h>

esp_err_t haptic_init(void);
void      haptic_play(uint8_t waveform_id);
```

**`src/main/audio.h` — add to `audio_cmd_e`:**
```c
AUDIO_CMD_HAPTIC_WARN_SINGLE,
AUDIO_CMD_HAPTIC_WARN_DOUBLE,
AUDIO_CMD_HAPTIC_BAD_STRONG,
AUDIO_CMD_HAPTIC_ESCALATION,
AUDIO_CMD_HAPTIC_CORRECTION,
AUDIO_CMD_HAPTIC_CAL_PROMPT,
AUDIO_CMD_HAPTIC_CAL_SUCCESS,
AUDIO_CMD_HAPTIC_CAL_FAIL,
```

**`src/main/audio.c` — add to `task_audio()` switch:**
```c
case AUDIO_CMD_HAPTIC_WARN_SINGLE:
    haptic_play(HAPTIC_WARN_SINGLE);
    break;
case AUDIO_CMD_HAPTIC_WARN_DOUBLE:
    haptic_play(HAPTIC_WARN_DOUBLE);
    break;
case AUDIO_CMD_HAPTIC_BAD_STRONG:
    haptic_play(HAPTIC_BAD_STRONG);
    break;
case AUDIO_CMD_HAPTIC_ESCALATION:
    haptic_play(HAPTIC_ESCALATION);
    break;
case AUDIO_CMD_HAPTIC_CORRECTION:
    haptic_play(HAPTIC_CORRECTION);
    break;
```

**`src/main/posture_fsm.c` — remap alert commands:**
```c
// WARNING entry (was AUDIO_CMD_WARN_BEEP)
enqueue_audio(AUDIO_CMD_HAPTIC_WARN_SINGLE);

// BAD entry (was AUDIO_CMD_BAD_ALERT alone)
enqueue_audio(AUDIO_CMD_HAPTIC_BAD_STRONG);
enqueue_audio(AUDIO_CMD_BAD_ALERT);

// BAD escalation (was AUDIO_CMD_BAD_ALERT alone)
enqueue_audio(AUDIO_CMD_HAPTIC_ESCALATION);
enqueue_audio(AUDIO_CMD_BAD_ALERT);

// Voice loop (was AUDIO_CMD_VOICE_CLIP alone)
enqueue_audio(AUDIO_CMD_HAPTIC_ESCALATION);
enqueue_audio(AUDIO_CMD_VOICE_CLIP);

// Correction (was AUDIO_CMD_CORRECTION_CONFIRM alone)
enqueue_audio(AUDIO_CMD_HAPTIC_CORRECTION);
enqueue_audio(AUDIO_CMD_CORRECTION_CONFIRM);
```

**`src/main/CMakeLists.txt` — add haptic.c:**
```cmake
idf_component_register(
    SRCS
        "main.c"
        "mpu6050.c"
        "audio.c"
        "posture_fsm.c"
        "haptic.c"
        "voice/sit_up_wav.c"
        "voice/thank_you_good_work_wav.c"
    INCLUDE_DIRS "."
)
target_link_libraries(${COMPONENT_LIB} PUBLIC m)
```

**`src/main/main.c` — add `haptic_init()` to boot sequence:**
```c
// After mpu6050_init(), before audio_init()
ret = haptic_init();
if (ret != ESP_OK) {
    ESP_LOGE(TAG, "Haptic init failed — continuing without haptics");
    // Non-fatal — device still works without haptics
}
```

### Testing procedure

After flash, work through each alert level deliberately:

1. **Single tap test** — hold sensor at 12° for 4 seconds → feel single tap
2. **BAD entry test** — hold sensor at 25° for 6 seconds → feel strong double tap + hear beep
3. **Escalation test** — hold BAD for 30 seconds → feel triple pulse + hear voice clip
4. **Correction test** — return to baseline → feel long reward pulse + hear "thank you"
5. **Pattern distinction test** — trigger each pattern, verify you can tell them apart by feel alone, eyes closed

### Pass criteria — ALL must be true

- [ ] DRV2605L detected on I2C bus at boot — `I (...) HAPTIC: DRV2605L initialised — LRA mode`
- [ ] MPU-6050 still working — no I2C conflict between 0x68 and 0x5A
- [ ] Single tap on WARNING — clearly felt, not startling
- [ ] Double tap on WARNING sustained — distinct from single tap
- [ ] Strong double tap on BAD entry — noticeably stronger than warning taps
- [ ] Triple pulse on escalation — distinct from BAD entry feel
- [ ] Long smooth buzz on correction — clearly positive, feels like a reward
- [ ] All 5 patterns distinguishable by feel alone (eyes closed test)
- [ ] No I2C errors in 10 minutes of active testing
- [ ] Audio still works correctly alongside haptics — no interference

### Feature branch
`feature/haptics` → PR into `release/v2-product`

---

## Phase 8 — Speaker Swap Validation

### Status: ⏳ Pending

### Objective
Confirm a 20mm 0.5W 8Ω speaker provides adequate volume for voice clips before
the speaker is committed to the PCB layout. This is the cheapest point to discover
the speaker is too quiet.

### Entry conditions
- Phase 7 complete and merged
- 20mm 8Ω 0.5W speaker purchased (CUI CMS-2009-SMT-TR or equivalent)

### Hardware needed
| Item | Where to buy | Approx cost |
|---|---|---|
| 20mm 8Ω 0.5W speaker | Digikey / Mouser / CUI | $1–3 |
| 2× alligator clips or solder | — | — |

### Wiring
Disconnect existing 3W 4Ω speaker from MAX98357A output terminals.
Connect 20mm 8Ω speaker in its place. No firmware changes needed.

> **IMPORTANT:** The existing speaker is 4Ω. The replacement is 8Ω. MAX98357A
> supports both. Output power at 8Ω from 5V supply ≈ 0.5W — correct and safe.
> Do NOT reconnect the 4Ω speaker after this test — it will not match the V2 PCB.

### Testing procedure

1. Flash unchanged V1 firmware (no code changes for this phase)
2. Power on — listen to boot tone volume at 0.5 metre distance
3. Trigger calibration — listen to cal prompt and success tones
4. Trigger WARNING → BAD → voice clip — evaluate "sit up straight" intelligibility
5. Trigger correction — evaluate "thank you good work" intelligibility
6. Test at 1 metre in a quiet room
7. Test at 1 metre with background noise (fan, music at low volume)

### Pass criteria — ALL must be true

- [ ] Boot tone audible at 1 metre — no strain to hear it
- [ ] "Sit up straight" clearly intelligible at 1 metre, quiet room
- [ ] "Sit up straight" intelligible at 1 metre with light background noise
- [ ] "Thank you good work" clearly intelligible at 1 metre
- [ ] Calibration tones (ascending 3-note) audible and distinct
- [ ] No distortion at maximum volume
- [ ] No rattling or resonance from the small speaker cone
- [ ] Volume acceptable for open-plan office use (not embarrassingly loud)

### If volume is insufficient
- Increase `VOL_VOICE` in `config.h` from 0.90f toward 1.0f
- If still insufficient at 1.0f, evaluate 28mm speaker as alternative
- Document the finding and decision in this file before proceeding

### Feature branch
`feature/speaker-swap` → PR into `release/v2-product`

---

## Phase 9 — Battery System Validation

### Status: ⏳ Pending

### Objective
Validate the MCP73831 charging circuit + AP2112K LDO + LiPo battery combination
before they appear on the V2 PCB. Catch any design errors at evaluation board
stage, not after PCB fabrication.

### Entry conditions
- Phase 8 complete and merged
- Battery components purchased or evaluation board available

### Hardware options (pick one)

**Option A (recommended) — Adafruit LiPo charger breakout:**
- Adafruit Micro LiPo charger #1904 (MCP73831 based)
- 350mAh LiPo with JST-PH connector
- AP2112K-3.3 SOT-23-5 breakout (available on eBay/AliExpress)
- Validates charging behaviour and LDO stability without custom PCB

**Option B — Small test PCB:**
- Design a minimal test PCB: MCP73831 + AP2112K + USB-C + JST + caps
- Order 5 units from JLCPCB (~$15 total)
- More rigorous, closer to final design

### What to build in firmware

**New file: `src/main/power.c`**

```c
#include "config.h"
#include "esp_log.h"
#include "esp_adc/adc_oneshot.h"
#include "power.h"
#include "audio.h"

static const char *TAG = "POWER";
static adc_oneshot_unit_handle_t s_adc_handle;

esp_err_t power_init(void)
{
    adc_oneshot_unit_init_cfg_t cfg = {
        .unit_id = ADC_UNIT_1,
    };
    esp_err_t ret = adc_oneshot_new_unit(&cfg, &s_adc_handle);
    if (ret != ESP_OK) return ret;

    adc_oneshot_chan_cfg_t chan_cfg = {
        .bitwidth = ADC_BITWIDTH_12,
        .atten    = ADC_ATTEN_DB_12,
    };
    return adc_oneshot_config_channel(s_adc_handle, VBAT_SENSE_CHANNEL, &chan_cfg);
}

float power_read_battery_voltage(void)
{
    int raw = 0;
    adc_oneshot_read(s_adc_handle, VBAT_SENSE_CHANNEL, &raw);
    float adc_v = (raw / 4095.0f) * 3.3f;
    return adc_v * VBAT_DIVIDER_RATIO;
}

void power_check_battery(void)
{
    float v = power_read_battery_voltage();
    ESP_LOGI(TAG, "Battery: %.2fV", v);

    if (v < LOW_BATTERY_CUTOFF_V) {
        ESP_LOGE(TAG, "Battery critical — entering deep sleep");
        audio_cmd_t cmd = { .type = AUDIO_CMD_BOOT_READY };  // repurpose as shutdown tone
        xQueueSend(g_audio_queue, &cmd, 0);
        vTaskDelay(pdMS_TO_TICKS(500));
        esp_deep_sleep_start();
    } else if (v < LOW_BATTERY_WARN_V) {
        ESP_LOGW(TAG, "Battery low");
        // Enqueue low battery beep — add AUDIO_CMD_LOW_BATTERY to enum
    }
}
```

**`config.h` additions:**
```c
#define VBAT_SENSE_CHANNEL      ADC_CHANNEL_6   // GPIO34 = ADC1 channel 6
#define VBAT_DIVIDER_RATIO      2.0f
#define LOW_BATTERY_WARN_V      3.5f
#define LOW_BATTERY_CUTOFF_V    3.3f
#define BATTERY_CHECK_INTERVAL_MS  60000
```

### Testing procedure

1. Connect LiPo charger breakout to USB-C — verify STAT LED shows charging
2. Measure LiPo voltage with multimeter while charging — confirm rises to 4.2V
3. Disconnect USB — confirm LDO still outputs 3.3V from LiPo
4. Run firmware with `power_check_battery()` logging every 60s
5. Let LiPo discharge to 3.5V — confirm warning fires
6. Let discharge to 3.3V — confirm deep sleep triggers
7. Charge back to full — confirm device wakes normally on reconnect
8. Time the discharge: run full firmware (IMU + FSM + occasional audio + haptic) — measure hours to 3.3V cutoff

### Pass criteria — ALL must be true

- [ ] LiPo charges via USB-C at ~100mA (verify with multimeter or USB meter)
- [ ] STAT LED: on while charging, off when done
- [ ] 3.3V stable on LDO output from 4.2V → 3.4V LiPo input
- [ ] Low battery warning fires correctly at 3.5V
- [ ] Deep sleep triggers at 3.3V cutoff — device does not crash before this
- [ ] Device wakes correctly on USB reconnect after deep sleep
- [ ] Full runtime (active firmware, no aggressive audio): ≥ 10 hours to cutoff
- [ ] No brownout or voltage glitch during audio playback (most current-intensive moment)

### Feature branch
`feature/power-system` → PR into `release/v2-product`

---

## Phase 10 — PCB V2 Design & Fabrication

### Status: 🔄 Design complete — awaiting JLCPCB order

### Objective
Design and fabricate the first custom PCB integrating all validated V2 components.
This is the highest-risk phase — layout errors cost money and 2–3 weeks of turnaround.
Every component must be validated in Phase 7–9 before being placed on this PCB.

### Entry conditions
- Phases 7, 8, and 9 complete and merged
- All waveform indices confirmed satisfactory (Phase 7)
- Speaker volume confirmed adequate (Phase 8)
- Battery circuit confirmed stable (Phase 9)
- KiCad or EasyEDA installed

### Schematic checklist (complete before layout)

- [x] ESP32-S3-MINI-1 with all bypass caps placed
- [x] Antenna keep-out zone marked as no-copper zone (3mm below module edge)
- [x] MPU-6050: 4.7kΩ pull-ups on SDA/SCL, 100nF bypass on VCC, AD0 to GND
- [x] DRV2605L: correct footprint, LRA pads broken out, EN tied HIGH
- [x] MAX98357A: correct footprint, SD_MODE to GPIO48, GAIN floating
- [x] MCP73831: PROG resistor 10kΩ (100mA charge), STAT pin to LED via 1kΩ
- [x] AP2112K: bulk caps 10µF in + out, 100nF bypass
- [x] USB-C: both CC pins to GND via 5.1kΩ, VBUS to polyfuse to MCP73831
- [x] USB-C D+/D- via USBLC6-2SC6 ESD protection to ESP32-S3 GPIO19/20
- [x] JST-PH 2-pin battery connector with correct pinout (+ on pin 1)
- [x] Both buttons with 10kΩ pull-up to 3.3V, 100nF debounce cap to GND
- [x] VBAT sense: 100kΩ–100kΩ divider from LiPo+ to GPIO34 to GND
- [x] Charge LED: green LED + 1kΩ from STAT to 3.3V

### Layout checklist (complete before Gerber export)

- [x] Board dimensions ≤ 50×38mm (actual: ~47.6 × 28.3mm)
- [x] Antenna keep-out enforced — no copper within 3mm of antenna area
- [x] All bypass caps placed close to their IC VCC pin
- [x] I2S traces (BCLK, WS, DOUT) routed
- [x] USB D+/D- routed
- [x] Speaker SPK_P/SPK_N traces routed (0.3mm, with ferrite beads FB1/FB2)
- [x] Power traces: VBUS/VBUS_FUSED 0.4mm, +3V3/VBAT 0.3mm (IPC-2221 verified)
- [x] GND: F.Cu + B.Cu copper pour with stitching vias
- [x] DRC passes — 0 errors, 0 unconnected, 2 cosmetic silk warnings only

### JLCPCB order checklist

- [x] Gerber files exported correctly (all 10 layers + 2 drill files)
- [x] DRC clean — 0 errors, 0 unconnected
- [x] ZIP ready: `hardware/pcb/v2/posture_tracker_v2_gerbers.zip`
- [ ] BOM exported in JLCPCB CSV format
- [ ] CPL (Component Placement List) exported
- [ ] All SMT components matched to JLCPCB parts library
- [ ] SMT assembly requested for top side only
- [ ] Order 5 prototype units (not 10 — there will be a revision)
- [ ] Specify ENIG surface finish for fine-pitch QFN/WLP pads
- [ ] Specify 1.6mm board thickness

### Post-receipt testing procedure

For each of the 5 PCBs:

1. Visual inspection — all ICs present, no shorts, no bridged pads
2. Continuity check on power rail — 3.3V and GND not shorted
3. Connect USB-C — verify 3.3V on LDO output before connecting battery
4. Connect LiPo — verify system powers on
5. Flash firmware via USB-C (hold BOOT button on SW1, press RESET)
6. Verify serial monitor output shows all modules initialised
7. Run Phase 7 haptic test — all 5 patterns
8. Run Phase 8 speaker test — voice clips intelligible
9. Run Phase 9 battery test — charge and discharge cycle
10. Soak test: run full firmware for 2 hours, monitor for faults

### Pass criteria — ALL must be true

- [ ] All 5 boards power on from USB-C
- [ ] All 5 boards flash successfully via native USB
- [ ] Boot log shows: MPU-6050, DRV2605L, MAX98357A all initialised
- [ ] Haptics working — all 5 waveform patterns fire
- [ ] Audio working — voice clips and tones play at adequate volume
- [ ] Battery charges from USB-C — STAT LED indicates correctly
- [ ] Both buttons respond — SW1 triggers recal, SW2 triggers snooze
- [ ] Board fits within enclosure dimensions (Phase 11 check)
- [ ] 2-hour soak test: no crashes, no resets, no stuck states
- [ ] At least 3 of 5 boards fully pass (accept 2 duds for manufacturing variance)

### Feature branch
`feature/pcb-schematic` → PR into `release/v2-product`
Commit all KiCad project files, Gerber exports, BOM, and CPL.

---

## Phase 11 — Full Integration, Enclosure & Wearable Validation

### Status: ⏳ Pending

### Objective
A complete wearable device worn for a real work session. PCB inside 3D printed
shoulder clip, battery connected, all features functional. This is the V2 product.

### Entry conditions
- Phase 10 complete — at least 3 fully passing PCBs in hand
- 3D printer available, or Shapeways/JLCPCB 3D printing ordered
- PETG filament (preferred: flexible enough to clip, rigid enough to hold)

### Enclosure design requirements

**Functional:**
- PCB slides into recessed pocket — retained without screws if possible (friction fit)
- Spring clip mechanism — clips onto shirt collar, bra strap, 1–2cm fabric
- USB-C port accessible from bottom edge without removing from clip
- Both buttons accessible on front face with short press travel
- Speaker grille on top face — 5–8 holes, 1mm diameter
- LRA motor recess on back face — motor contacts body when worn

**Dimensional targets:**
- Clip opening: 15mm max gap, 5N clip force (firm but not damaging)
- Overall: 45×38×16mm
- Pocket for PCB: 47×37×9mm (1mm tolerance each side)
- Battery slot: behind PCB pocket, 37×27×6mm

**CAD files:**
- Design in Fusion 360, FreeCAD, or Onshape (all free tier)
- Export STL for printing
- Commit STL + source file to `feature/enclosure` branch

### Wearability testing procedure

1. Print 2 enclosure prototypes — check fit with PCB before soldering anything
2. Assemble one complete unit: PCB + LiPo + enclosure
3. Clip to shirt collar at left shoulder — sensor mounting orientation
4. Power on — confirm calibration prompt plays and is audible when worn
5. Calibrate in sitting position at desk
6. Work for 4 hours wearing the device:
   - Normal desk work (typing, reading)
   - One 30-minute meeting (test snooze button)
   - Deliberate slouching every 30 minutes to verify alerts fire
   - Check battery level at end of session
7. Repeat with 2 different people if possible (sensor position may vary)

### Pass criteria — ALL must be true

- [ ] Device clips securely to shirt — does not fall during normal movement
- [ ] Calibration completes correctly in shoulder-mounted orientation
- [ ] WARNING haptic fires correctly during desk work slouch — not during typing
- [ ] BAD audio fires after sustained poor posture — not from vibration/walking
- [ ] Snooze button accessible and works during meeting scenario
- [ ] Voice clip audible while wearing — speaker facing outward is sufficient
- [ ] Device worn for 4+ hours — no crashes, no false positives from desk vibration
- [ ] Battery lasts full 4-hour session with >50% charge remaining
- [ ] Enclosure: no sharp edges, no accidental button presses, clip does not mark clothing
- [ ] Serial log: clean state transitions, no spurious events throughout session

---

## Phase Summary Table

| Phase | Description | Branch | Status | Hardware |
|---|---|---|---|---|
| 7 | Haptic validation — breadboard | `feature/haptics` | ⏳ Next | 📦 Parts ordered |
| 8 | Speaker swap validation | `feature/speaker-swap` | ⏳ Next | 📦 Parts ordered |
| 9 | Battery system validation | `feature/power-system` | ⏳ Pending | 📦 Parts ordered |
| 10 | PCB V2 design + fabrication | `feature/pcb-schematic` | 🔄 Design complete | Schematic ✅ ERC clean. Layout ✅ DRC clean. Gerbers ✅ `hardware/pcb/v2/`. JLCPCB order ⏳ pending |
| 11 | Full integration + enclosure | `feature/enclosure` | ⏳ Pending | 🛒 Order after Phase 10 |

---

## Hardware Shopping List (Phases 7–9)

Order these before starting Phase 7. Most arrive in 2–5 days.

| Item | Source | Est. cost | Needed for |
|---|---|---|---|
| Adafruit DRV2605L breakout #2305 | adafruit.com | $7.95 | Phase 7 |
| 10mm LRA motor (Adafruit #1201 or Digikey) | adafruit.com / digikey.com | $4.00 | Phase 7 |
| 20mm 8Ω 0.5W speaker | digikey.com / mouser.com | $2.00 | Phase 8 |
| Adafruit LiPo charger breakout #1904 | adafruit.com | $6.95 | Phase 9 |
| 350mAh LiPo with JST-PH #2750 | adafruit.com | $6.95 | Phase 9 |
| AP2112K-3.3 breakout or bare SOT-23-5 | digikey.com | $1.00 | Phase 9 |
| **Total** | | **~$30** | Phases 7–9 |

---

## Known Risks & Mitigations

| Risk | Phase | Mitigation |
|---|---|---|
| I2C address conflict (MPU-6050 + DRV2605L) | 7 | Different addresses: 0x68 vs 0x5A — no conflict, verified in spec |
| LRA waveforms feel similar / undifferentiated | 7 | Test all 123 indices, document best candidates before committing |
| 20mm speaker too quiet for voice clips | 8 | Test before PCB order — can switch to 28mm if needed |
| Brownout during audio playback on LiPo | 9 | AP2112K has 600mA headroom, add 22µF bulk cap on output |
| ESP32-S3 antenna detuned by PCB copper | 10 | Enforce keep-out in layout — check with BLE range test post-fab |
| MAX98357A WLP-16 bridged pads (tiny IC) | 10 | Use ENIG finish, inspect under magnification, reflow stencil |
| Clip spring force too strong / marks clothing | 11 | Print multiple prototypes with varying wall thickness |
| Sensor calibration offset differs per person | 11 | Calibration routine handles this — test with 2+ people |

---

*Branch: release/v2-product*
*Created: 2026-04-26*
*Reference: CLAUDE.md — full architecture and component decisions*

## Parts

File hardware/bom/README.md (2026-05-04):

# BOM (Bill of Materials)

## bom_v2_master.csv — master BOM (source of truth)

Full component list for PCB V2. Update this as components are confirmed.
Export JLCPCB-formatted BOM from KiCad when schematic is complete.

## Current confirmed components (as of 2026-05-03)

| Ref | Component | Part Number | Supplier | Unit Cost | Status |
|---|---|---|---|---|---|
| U1 | ESP32-S3-MINI-1-N8 | ESP32-S3-MINI-1-N8 | Espressif / Digikey | $2.50 | ⬜ Not ordered |
| U2 | MPU-6050 | MPU-6050 | Digikey 1428-1011-1-ND | $0.30 | ⬜ Not ordered |
| U3 | DRV2605L haptic driver | DRV2605LDGSR | Digikey 296-43883-1-ND | $1.20 | ⬜ Not ordered |
| U4 | MAX98357A audio amp | MAX98357AEWL | Digikey MAX98357AEWL+CT-ND | $1.50 | ⬜ Not ordered |
| U5 | MCP73831 LiPo charger | MCP73831T-2ACI/OT | Digikey MCP73831T-2ACI/OTCT-ND | $0.25 | ⬜ Not ordered |
| U6 | AP2112K-3.3 LDO | AP2112K-3.3TRG1 | Digikey AP2112K-3.3TRG1DICT-ND | $0.15 | ⬜ Not ordered |
| U7 | USBLC6-2SC6 ESD protection | USBLC6-2SC6Y | Digikey 497-5235-1-ND | $0.20 | ⬜ Not ordered |
| M1 | LRA motor | Vybronics VG1030001XH | Digikey 1670-VG1030001XH-ND | $2.96 | ✅ Ordered × 3 |
| LS1 | 20mm 8Ω 1W speaker | MECCANIXITY 20mm | Amazon | $2.12 | ✅ Ordered × 4 |
| BT1 | 350mAh LiPo | Adafruit #2750 | Digikey 1528-1858-ND | $6.95 | ✅ Ordered × 2 |
| — | LiPo charger breakout | Adafruit #1904 | adafruit.com | $6.95 | ✅ Ordered × 1 — Phase 9 validation only, not on PCB |
| J1 | USB-C connector | HRO TYPE-C-31-M-12 | LCSC C165948 / Digikey | $0.35 | ⬜ Not ordered |
| J2 | JST-PH 2-pin | JST-PH | Digikey 455-1719-ND | $0.10 | ⬜ Not ordered |
| SW1 | Button BOOT/CAL | Alps SKRPABE010 | Digikey SKRPABE010CT-ND | $0.10 | ⬜ Not ordered |
| SW2 | Button SNOOZE | Alps SKRPABE010 | Digikey SKRPABE010CT-ND | $0.10 | ⬜ Not ordered |
| SW3 | Button RESET | Alps SKRPABE010 | Digikey SKRPABE010CT-ND | $0.10 | ⬜ Not ordered |
| LED2 | Snooze indicator LED | Generic 0805 green | Digikey 160-1446-1-ND | $0.05 | ⬜ Not ordered |

## Passives (order with Phase 10)

| Value | Package | Digikey Part # | Qty | Status |
|---|---|---|---|---|
| 4.7kΩ resistor | 0402 | 311-4.7KLRCT-ND | 50 | ⬜ Not ordered |
| 10kΩ resistor | 0402 | 311-10.0KLRCT-ND | 50 | ⬜ Not ordered |
| 100kΩ resistor | 0402 | 311-100KLRCT-ND | 20 | ⬜ Not ordered |
| 5.1kΩ resistor | 0402 | 311-5.10KLRCT-ND | 50 | ⬜ Not ordered |
| 1kΩ resistor | 0402 | 311-1.00KLRCT-ND | 50 | ⬜ Not ordered |
| 100nF cap | 0402 | 311-1375-1-ND | 50 | ⬜ Not ordered |
| 1µF cap | 0402 | 311-1543-1-ND | 20 | ⬜ Not ordered |
| 4.7µF cap | 0402 | 399-C17 (C17 VBUS_FUSED) | 10 | ⬜ Not ordered |
| 10µF cap | 0805 | 399-8419-1-ND | 20 | ⬜ Not ordered |
| 22µF cap | 0805 | 399-8423-1-ND | 10 | ⬜ Not ordered |
| 47µF cap | 0805 | 399-8425-1-ND | 5 | ⬜ Not ordered |
| 500mA polyfuse | 0805 | MINISMDC050F/24-2CT-ND | 5 | ⬜ Not ordered |
| Green LED | 0805 | 160-1446-1-ND | 10 | ⬜ Not ordered |

## Estimated total BOM cost per unit

| Category | Cost |
|---|---|
| ICs | ~$6.00 |
| Passives | ~$1.00 |
| Connectors + buttons | ~$0.70 |
| Motor + speaker | ~$5.00 |
| Battery | ~$7.00 |
| **Total per unit** | **~$20** |

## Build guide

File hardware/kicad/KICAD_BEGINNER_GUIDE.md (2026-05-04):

# KiCad Beginner Guide — Posture Tracker V2

> This guide is written specifically for this project. It covers only what you
> need to know to draw this schematic and lay out this PCB. Not a general tutorial.
> Read KICAD_CONTEXT.md first to understand what needs to be built.

---

## Step 0 — Install KiCad

1. Go to kicad.org → Download → KiCad 8.x for macOS
2. Install and open KiCad
3. On first launch it will download the standard symbol and footprint libraries (~2GB)
4. Let it finish before doing anything else

---

## Step 1 — Create the Project

1. Open KiCad
2. File → New Project
3. Navigate to `hardware/kicad/posture_tracker_v2/`
4. Name it: `posture_tracker_v2`
5. KiCad creates three files automatically:
   - `posture_tracker_v2.kicad_pro` — project file
   - `posture_tracker_v2.kicad_sch` — schematic (blank)
   - `posture_tracker_v2.kicad_pcb` — PCB layout (blank)

---

## Step 2 — Understand the KiCad Window

When you open KiCad you see the **Project Manager**:
```
┌─────────────────────────────────────┐
│  KiCad Project Manager              │
│                                     │
│  [Schematic Editor]  ← draw here first
│  [PCB Editor]        ← do this after schematic
│  [Symbol Editor]     ← for custom symbols
│  [Footprint Editor]  ← for custom footprints
│  [Gerber Viewer]     ← check output files
└─────────────────────────────────────┘
```

**Always work in this order: Schematic first → PCB second.**
Never open the PCB editor until the schematic is complete.

---

## Step 3 — Schematic Editor Basics

Click **Schematic Editor** to open it.

### Essential keyboard shortcuts (memorise these)

| Key | Action |
|---|---|
| `A` | Add symbol (place a component) |
| `W` | Add wire |
| `P` | Add power symbol (+3V3, GND etc) |
| `L` | Add net label (name a wire) |
| `R` | Rotate selected item |
| `G` | Grab (move while keeping connections) |
| `E` | Edit properties of selected item |
| `Delete` | Delete selected item |
| `Ctrl+Z` | Undo |
| `Scroll` | Zoom in/out |
| `Middle click drag` | Pan |

### The golden rule of schematics
**Wires must touch pins to make a connection.**
A wire that passes near a pin but does not touch it is NOT connected.
You will see a small green dot where a proper connection is made.

---

## Step 4 — How to Place a Component

1. Press `A` → Symbol chooser opens
2. Search by name (e.g. "MPU-6050" or "MCP73831")
3. Click the symbol → click OK → click on schematic to place
4. Press `Escape` when done placing

**If a component is not in the library:**
- Go to snapeda.com
- Search by exact part number
- Download KiCad format
- In KiCad: Preferences → Manage Symbol Libraries → add the downloaded file

---

## Step 5 — How to Add Power Symbols

Power symbols (+3V3, GND, VBAT) are special symbols that connect any wire
with the same label without drawing a physical wire between them.

1. Press `P` → Power symbol chooser
2. Search "GND" → place wherever you need ground
3. Search "+3V3" → if not found, create it:
   - Add a power symbol named `+3V3`
   - All nets labelled `+3V3` connect automatically

**Use power symbols everywhere instead of drawing long wires across the schematic.**
Your schematic will be much cleaner.

---

## Step 6 — How to Label a Net

Net labels connect wires that are far apart without drawing a line between them.
Same as power symbols but for signal nets (SDA, SCL, I2S_BCLK etc).

1. Press `L` → type the net name exactly as in KICAD_CONTEXT.md
2. Place the label at the end of the wire
3. Any other wire with the same label is connected — even on a different part of the schematic

**Example:** Put label `SDA` on the MPU-6050 SDA pin wire.
Put label `SDA` on the DRV2605L SDA pin wire.
They are now connected even though they're not physically joined by a wire.

---

## Step 7 — How to Add a Resistor or Capacitor

1. Press `A` → search "R" for resistor or "C" for capacitor
2. Choose from the Device library (Device:R or Device:C)
3. Place it
4. Press `E` to edit → set Value field to "4.7k" or "100n" etc

**For bypass caps:** place them right next to the IC they bypass.
**For pull-up resistors:** place them between the signal net and +3V3.

---

## Step 8 — No-Connect Markers

Unused pins must have a no-connect marker (X) so KiCad doesn't flag them as errors.

1. Press `Q` → no-connect tool
2. Click on any pin that is intentionally unconnected

Do this for all unused GPIO pins on the ESP32-S3.

---

## Step 9 — Running ERC (Electrical Rules Check)

After finishing each block, run ERC to catch mistakes.

Inspect → Electrical Rules Checker → Run ERC

Common errors and fixes:
| Error | Fix |
|---|---|
| Pin not connected | Add wire or no-connect marker |
| Power pin not driven | Add PWR_FLAG symbol to +3V3 and GND nets |
| Net has no driver | Check power symbols are correct |
| Duplicate reference | Two components have same ref — renumber |

**Target: zero ERC errors before moving to PCB.**

---

## Step 10 — Assigning Footprints

Every schematic symbol needs a PCB footprint assigned to it.
Without this, the PCB editor doesn't know what physical shape to use.

Tools → Assign Footprints

For each component, find the footprint:
| Component | Footprint to assign |
|---|---|
| Resistors 0402 | Resistor_SMD:R_0402_1005Metric |
| Caps 0402 | Capacitor_SMD:C_0402_1005Metric |
| Caps 0805 | Capacitor_SMD:C_0805_2012Metric |
| MCP73831 | Package_TO_SOT_SMD:SOT-23-5 |
| AP2112K | Package_TO_SOT_SMD:SOT-23-5 |
| MPU-6050 | Download from SnapEDA |
| DRV2605L | Download from SnapEDA (WSON-12) |
| MAX98357A | Download from SnapEDA (WLP-16) |
| ESP32-S3-MINI-1U | Download from SnapEDA or Espressif |

---

## Step 11 — Exporting Netlist to PCB

When schematic is complete and ERC is clean:

Tools → Update PCB from Schematic

This pushes all components and their connections into the PCB editor.
Components appear as a pile in the middle — you then arrange and route them.

---

## Step 12 — PCB Editor Basics (do after schematic)

### Essential keyboard shortcuts

| Key | Action |
|---|---|
| `X` | Route track (draw copper trace) |
| `R` | Rotate |
| `F` | Flip to other side |
| `E` | Edit properties |
| `U` | Select connected track |
| `I` | Select entire net |
| `Ctrl+B` | Fill all zones (pour copper) |
| `D` | DRC (design rule check) |

### PCB layer guide

| Layer | Colour | Purpose |
|---|---|---|
| F.Cu | Red | Top copper — component side |
| B.Cu | Blue | Bottom copper — solder side |
| F.Silkscreen | Yellow | Component labels on top |
| F.Courtyard | Pink | Component keepout boundary |
| Edge.Cuts | Yellow | Board outline |

### Trace width rules for this board

| Net type | Min width |
|---|---|
| Signal (SDA, SCL, GPIO) | 0.15mm |
| 3.3V power rail | 0.5mm |
| Battery / speaker | 1.0mm |
| USB D+/D- | 0.2mm matched length |

---

## Step 13 — Board Outline

Before placing any components, draw the board outline.

1. Select layer: Edge.Cuts
2. Place → Rectangle
3. Draw 45×35mm rectangle
4. This is your board boundary — nothing goes outside it

---

## Step 14 — Component Placement Order

Place in this order (most critical first):

1. **ESP32-S3-MINI-1U** — centre-top, antenna overhanging or at board edge
2. **MPU-6050** — centre of board, away from switching ICs
3. **DRV2605L** — near I2C bus traces
4. **MAX98357A** — near speaker connector, bottom-right area
5. **MCP73831 + AP2112K** — near USB-C connector
6. **USB-C J1** — bottom edge
7. **Battery J2** — top edge, opposite USB-C
8. **Buttons SW1, SW2** — front face (left edge)
9. **Speaker LS1** — right edge, facing outward
10. **All passives** — next to their respective ICs

---

## Step 15 — Antenna Keep-Out Zone

This is critical and easy to forget.

1. Select layer: F.Cu (or any copper layer)
2. Place → Zone → choose "No copper zone" (keep-out)
3. Draw a rectangle covering 3mm below the antenna edge of U1
4. Set it to exclude all copper layers

Without this, your BLE/WiFi range will be terrible.

---

## Step 16 — Running DRC (Design Rule Check)

Inspect → Design Rules Checker → Run DRC

Common errors:
| Error | Fix |
|---|---|
| Clearance violation | Traces too close — move or reroute |
| Unrouted net | A connection from schematic not yet drawn |
| Footprint outside board | Move component inside Edge.Cuts |
| Silkscreen overlap | Move labels |

**Target: zero DRC errors before exporting Gerbers.**

---

## Step 17 — Exporting Gerbers for JLCPCB

File → Fabrication Outputs → Gerbers

Settings for JLCPCB:
- Include layers: F.Cu, B.Cu, F.Silkscreen, B.Silkscreen, F.Mask, B.Mask, Edge.Cuts
- Format: Gerber X2
- Output folder: `hardware/kicad/posture_tracker_v2/gerbers/`

Also export:
- Drill files: File → Fabrication Outputs → Drill Files
- BOM: File → Fabrication Outputs → BOM
- Component placement: File → Fabrication Outputs → Component Placement

Zip the gerbers folder → upload to jlcpcb.com

---

## Order of Work — Session by Session

```
Session 1: Install KiCad, create project, download missing symbols from SnapEDA
Session 2: Draw Block 1 (Power) — USB-C, MCP73831, AP2112K, LiPo connector
Session 3: Draw Block 2 (MCU) — ESP32-S3-MINI-1U, bypass caps, GPIO assignments
Session 4: Draw Block 3+4 (IMU + Haptic) — MPU-6050, DRV2605L, shared I2C
Session 5: Draw Block 5 (Audio) — MAX98357A, speaker connector
Session 6: Draw Block 6+7 (Buttons, LED, VBAT sense)
Session 7: Run ERC, fix all errors, assign all footprints
Session 8: Export netlist to PCB, draw board outline, place components
Session 9: Route all traces, pour ground plane
Session 10: Run DRC, fix errors, export Gerbers
```

---

## Resources

- KiCad official docs: docs.kicad.org
- SnapEDA (symbols + footprints): snapeda.com
- Espressif KiCad library: github.com/espressif/kicad-libraries
- JLCPCB design rules: jlcpcb.com/capabilities/pcb-capabilities
- Phil's Lab KiCad tutorial (YouTube): search "Phil's Lab KiCad 8"

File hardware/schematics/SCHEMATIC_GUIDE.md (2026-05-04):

# Schematic Design Guide — Posture Tracker V2

> **Purpose:** This file explains the reasoning behind every block, every component,
> and every design decision in the V2 schematic. Use this as a reference when
> reviewing, debugging, or extending the schematic in future sessions.
> Read this before touching any schematic block.

---

## SPICE Simulation Results

Simulations run using KiCad 8 built-in ngspice simulator on 2026-05-02.

### Simulation 1 — EN Reset RC Delay (R11 + C11)

**Circuit:** +3V3 → R11 (10kΩ) → ESP_EN → C11 (100nF) → GND

**Result:** ✅ PASS
- Time constant τ = R11 × C11 = 10kΩ × 100nF = 1ms
- EN pin reaches 63% of 3.3V (2.1V) at t = 1ms
- EN pin reaches 99% (3.27V) at t = 5ms
- ESP32 boots cleanly after power rail is fully stable
- Design is correct — no changes needed

### Simulation 2 — I2C Pull-up Rise Time (R1 + C_SDA)

**Circuit:** +3V3 → R1 (4.7kΩ) → SDA → C_load (10pF) → GND

**Result:** ✅ PASS (with note)
- Rise time measured ~900ns at 400kHz Fast Mode
- I2C spec allows up to 1250ns (half period at 400kHz)
- 4.7kΩ is the standard recommended value per I2C spec for Fast Mode
- On the actual PCB (45×35mm, short traces), bus capacitance will be 5–15pF
- Real-world rise time will be well within spec
- Design is correct — no changes needed

---

## Overview — What the Schematic Does

The posture tracker is a wearable shoulder-mounted device. It detects slouching
using an IMU sensor and alerts the user through haptic vibration (early warning)
and audio (escalating alert). It runs on a LiPo battery charged over USB-C.

The schematic is split into 7 logical blocks. Each block is drawn separately,
verified with ERC, then connected to the others through net labels.

```
USB-C (J1)
  → Polyfuse (F1)
    → MCP73831 charger (U5) → LiPo battery (J2)
  → AP2112K LDO (U6) → 3.3V rail → everything else

3.3V rail powers:
  → ESP32-S3-MINI-1U (U1)     ← brain
  → MPU-6050 (U2)             ← posture sensor
  → DRV2605L (U3)             ← haptic driver
  → MAX98357A (U4)            ← audio amplifier
  → Buttons SW1, SW2          ← user input
  → LED1                      ← charge indicator
```

---

## Block 1 — Power System

### What it does
Takes 5V USB input and produces a stable 3.3V rail for the whole board.
Also manages LiPo battery charging safely.

### Components and why each one exists

**J1 — USB-C Receptacle (GCT USB4135-GF-A)**
The charging and programming port. USB-C chosen over Micro-USB because:
- Reversible — no wrong-way insertion
- Modern standard — compatible with all new chargers
- Supports USB 2.0 for ESP32-S3 native USB (programming + serial monitor)

CC1 and CC2 pins: Both must have 5.1kΩ resistors (R4, R5) to GND.
These resistors signal to the USB-C charger "I am a device that needs 5V/500mA."
Without them, USB-C power delivery chargers will not supply current. This is
non-negotiable — missing CC resistors = device does not charge.

**F1 — Polyfuse 500mA**
Resettable fuse between USB VBUS and the charger IC.
If a short circuit occurs on the board, F1 trips and cuts power before components
are damaged. It resets automatically when the short is removed and power is cycled.
500mA chosen to match USB 2.0 current limit.

**U5 — MCP73831T-2ACI/OT (LiPo Charger)**
Single-cell LiPo/Li-Ion charge management IC in SOT-23-5 package.
Charges the battery from USB 5V input.

Key connections:
- VDD → VBUS_FUSED (5V from USB through polyfuse) — charger input power
- VBAT → battery positive terminal (J2 pin 1)
- VSS → GND
- PROG → 10kΩ R3 → GND — sets charge current to 100mA (Icharge = 1000/RPROG mA)
- STAT → charge status output (open drain, active low when charging)

Why 100mA charge current: Conservative for a 350mAh cell. Full charge in ~3.5 hours.
Keeps heat low and extends battery cycle life. Do not reduce R3 below 10kΩ without
recalculating — lower resistance = higher current = risk of overheating.

**J2 — JST-PH 2-pin (Battery Connector)**
Where the LiPo battery plugs in. JST-PH chosen because:
- Keyed — physically impossible to insert backwards
- Standard connector used by Adafruit, SparkFun batteries
- Pin 1 = positive (red wire), Pin 2 = negative (black wire)
Always verify polarity before connecting a battery.

**U6 — AP2112K-3.3TRG1 (LDO Voltage Regulator)**
Low-dropout linear regulator. Takes LiPo voltage (3.0–4.2V as battery drains)
and outputs a rock-solid 3.3V for all ICs.

Key connections:
- VIN → VBAT (battery voltage)
- EN → VIN (always-on — no software power control in V2)
- VOUT → +3V3 rail (powers everything)
- C6 (10µF) on VIN — input bulk capacitor, prevents LDO instability
- C7 (10µF) on VOUT — output bulk capacitor, filters load transients

Why not use the charger output directly? The charger outputs variable voltage
(battery voltage). The ESP32 and all sensors need stable 3.3V. The LDO provides
this regulation. During USB charging, the LDO draws from the battery which is
simultaneously being charged — this is correct and safe.

**LED1 + R6 (Charge Indicator)**
Green LED connected between 3.3V and the MCP73831 STAT pin.
STAT is open-drain: pulls low when charging, floats when complete.
When STAT is low → current flows → LED lights up = charging.
When charging complete → STAT floats → LED off.
R6 (1kΩ) limits current to ~2.3mA — safe for the LED and STAT pin.

**PWR_FLAG symbols**
KiCad ERC requires PWR_FLAG on power nets to confirm they are driven.
One PWR_FLAG on VBUS_FUSED, one on GND. These are schematic-only symbols
with no physical component.

### Net names used
| Net | Voltage | Description |
|---|---|---|
| VBUS | 5V | Raw USB input |
| VBUS_FUSED | 5V | USB after polyfuse |
| VBAT | 3.0–4.2V | LiPo battery voltage |
| +3V3 | 3.3V | Regulated rail for all ICs |
| GND | 0V | Common ground |

---

## Block 2 — MCU (ESP32-S3-MINI-1U)

### What it does
The brain of the device. Runs all firmware, reads sensors over I2C,
drives haptics and audio over I2S, manages user input, controls power.

### Components and why each one exists

**U1 — ESP32-S3-MINI-1U (Main Microcontroller)**
Stamp module (15.6×12mm) containing ESP32-S3 SoC, 8MB flash, antenna.
Chosen over original ESP32 Dev Kit because:
- 10× smaller footprint — fits in wearable form factor
- Native USB — no USB-to-UART chip needed, saves cost and space
- BLE 5.0 — future app connectivity without extra hardware
- Dual-core 240MHz — handles audio + sensor fusion simultaneously
- 3.3V native — directly compatible with all other ICs on this board

**C1 — 100nF bypass cap on 3V3 pin**
Decoupling capacitor placed as close as possible to the 3V3 pin.
Filters high-frequency switching noise generated by the CPU cores and
RF circuitry. Without this, noise couples into I2C and I2S signal lines
causing communication errors and audio glitches.

**R11 + C11 — EN reset circuit**
The EN (enable) pin controls whether the ESP32 is running or held in reset.
- R11 (10kΩ): pulls EN high → ESP32 runs normally
- C11 (100nF): charges slowly on power-up, delays EN going high by ~1ms
  This ensures power rails are fully stable before the ESP32 starts.
  Without this cap, the ESP32 may start before 3.3V is stable → corrupt boot.
A reset button (not in V2) would connect between EN and GND.

### GPIO assignments and why

| GPIO | Net | Reason for choice |
|---|---|---|
| GPIO8 | SDA | Left side of module, no special function, I2C capable |
| GPIO9 | SCL | Left side, adjacent to GPIO8 — keeps I2C traces short |
| GPIO26 | I2S_BCLK | I2S capable, right side |
| GPIO21 | I2S_DOUT | I2S capable, right side, near BCLK |
| GPIO33 | I2S_WS | I2S capable, right side, near BCLK and DOUT |
| GPIO34 | VBAT_SENSE | ADC1 channel — ADC2 unusable with WiFi/BLE |
| GPIO35 | BTN_SNOOZE | Any GPIO, no special function |
| GPIO0 | BTN_CAL | BOOT pin — also used for firmware download mode |
| GPIO48 | AUDIO_SD | Any GPIO, controls MAX98357A mute |
| GPIO19 | USB_DM | Fixed — hardware USB D- on ESP32-S3 |
| GPIO20 | USB_DP | Fixed — hardware USB D+ on ESP32-S3 |

Note: GPIO22–25 do not exist on ESP32-S3 (they existed on original ESP32).
All unused GPIOs have no-connect markers to satisfy ERC.

---

## Block 3 — IMU (MPU-6050)

### What it does
Measures the tilt angle of the device. The firmware compares the current
angle to the calibrated baseline to detect slouching.

### Components and why each one exists

**U2 — MPU-6050 (6-axis IMU)**
Combines 3-axis accelerometer and 3-axis gyroscope in one IC.
Only the accelerometer is used in V2 — it measures gravity direction,
which gives absolute tilt angle. The gyroscope is unused (adds drift
without a fusion filter).

Communicates over I2C at address 0x68 (AD0 tied to GND).

Key connections:
- VDD → +3V3 (main power)
- VLOGIC → +3V3 (I2C interface voltage — must match ESP32 logic level)
- GND → GND
- SDA → SDA net (shared I2C bus with DRV2605L)
- SCL → SCL net (shared I2C bus with DRV2605L)
- AD0 → GND (I2C address 0x68)
- All other pins → no-connect

**C2 — 100nF bypass cap on VDD**
Precision sensor — power supply noise directly corrupts accelerometer readings.
A noise spike of even 10mV can cause a false posture alert. C2 placed as
close as possible to VDD pin filters this noise at the source.

**R1 — 4.7kΩ SDA pull-up**
**R2 — 4.7kΩ SCL pull-up**
I2C is an open-drain bus. No IC on the bus drives lines high — they can only
pull low. The pull-up resistors pull SDA and SCL to 3.3V when no IC is
pulling them low. Without pull-ups, I2C does not work at all.

4.7kΩ chosen for 400kHz Fast Mode operation. Lower resistance = faster edges
but more current. Higher resistance = slower edges, unreliable at 400kHz.

IMPORTANT: Pull-ups are placed ONCE here in Block 3. Do NOT add more pull-ups
in Block 4 (DRV2605L). Extra pull-ups on the same bus lower the effective
resistance and overdrive the bus.

---

## Block 4 — Haptic Driver (DRV2605L + LRA Motor)

### What it does
Drives the LRA (Linear Resonant Actuator) haptic motor to produce
precise vibration patterns as early-warning posture alerts.

> To be completed when Block 4 is drawn.

---

## Block 5 — Audio Amplifier (MAX98357A + Speaker)

### What it does
Amplifies I2S audio from the ESP32 and drives the 8Ω speaker for
audio alerts and voice clips.

> To be completed when Block 5 is drawn.

---

## Block 6 — Buttons + Charge LED

### What it does
Two tactile buttons for user input (recalibrate posture baseline,
snooze alerts). One LED for battery charge status.

> To be completed when Block 6 is drawn.

---

## Block 7 — Battery Voltage Sense

### What it does
A resistor voltage divider scales the LiPo voltage (3.0–4.2V) down
to the ADC range (0–3.3V) so firmware can estimate remaining battery.

> To be completed when Block 7 is drawn.

---

## Design Rules — Never Violate These

1. **USB-C CC pins**: Both CC1 and CC2 must have 5.1kΩ to GND. Missing one = no charging.
2. **I2C pull-ups**: Only one set (R1, R2) for the entire bus. Never add more.
3. **MCP73831 PROG**: 10kΩ = 100mA charge current. Do not change without recalculating.
4. **ESP32 antenna keep-out**: 3mm copper-free zone under antenna edge on PCB.
5. **Bypass caps**: Place within 1mm of each IC VCC pin on same copper layer.
6. **JST-PH polarity**: Pin 1 = positive. Verify before connecting battery.
7. **AD0 on MPU-6050**: Must be tied to GND. Floating = undefined I2C address.
8. **MAX98357A SD_MODE**: Must be driven by GPIO48. Never leave floating.

---

## Net Names Reference

| Net | Voltage | Connected to |
|---|---|---|
| VBUS | 5V | J1 VBUS pin |
| VBUS_FUSED | 5V | F1 output → U5 VDD |
| VBAT | 3.0–4.2V | J2 pin 1, U5 VBAT, U6 VIN |
| +3V3 | 3.3V | U6 VOUT → all ICs |
| GND | 0V | All ground connections |
| SDA | signal | U1 GPIO8, U2 SDA, U3 SDA, R1 |
| SCL | signal | U1 GPIO9, U2 SCL, U3 SCL, R2 |
| I2S_BCLK | signal | U1 GPIO26, U4 BCLK |
| I2S_WS | signal | U1 GPIO33, U4 LRCLK |
| I2S_DOUT | signal | U1 GPIO21, U4 DIN |
| AUDIO_SD | signal | U1 GPIO48, U4 SD_MODE |
| BTN_CAL | signal | U1 GPIO0, SW1 |
| BTN_SNOOZE | signal | U1 GPIO35, SW2 |
| VBAT_SENSE | signal | U1 GPIO34, voltage divider |
| USB_DM | signal | U1 GPIO19, J1 D- |
| USB_DP | signal | U1 GPIO20, J1 D+ |
| STAT | signal | U5 STAT, LED1 cathode |
| ESP_EN | signal | U1 EN, R11, C11 |

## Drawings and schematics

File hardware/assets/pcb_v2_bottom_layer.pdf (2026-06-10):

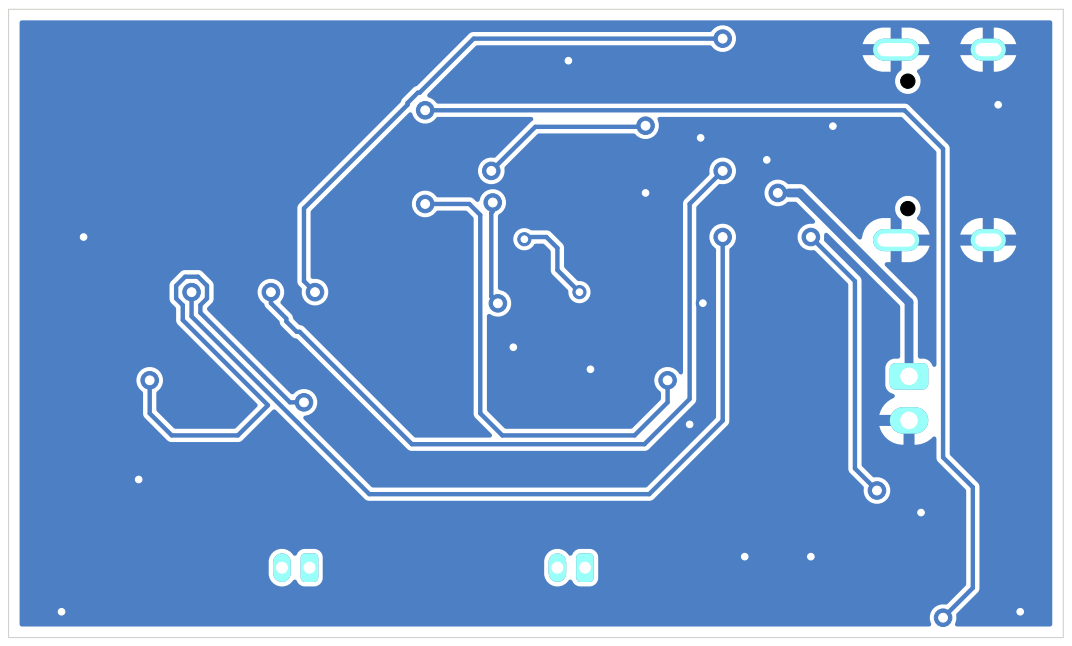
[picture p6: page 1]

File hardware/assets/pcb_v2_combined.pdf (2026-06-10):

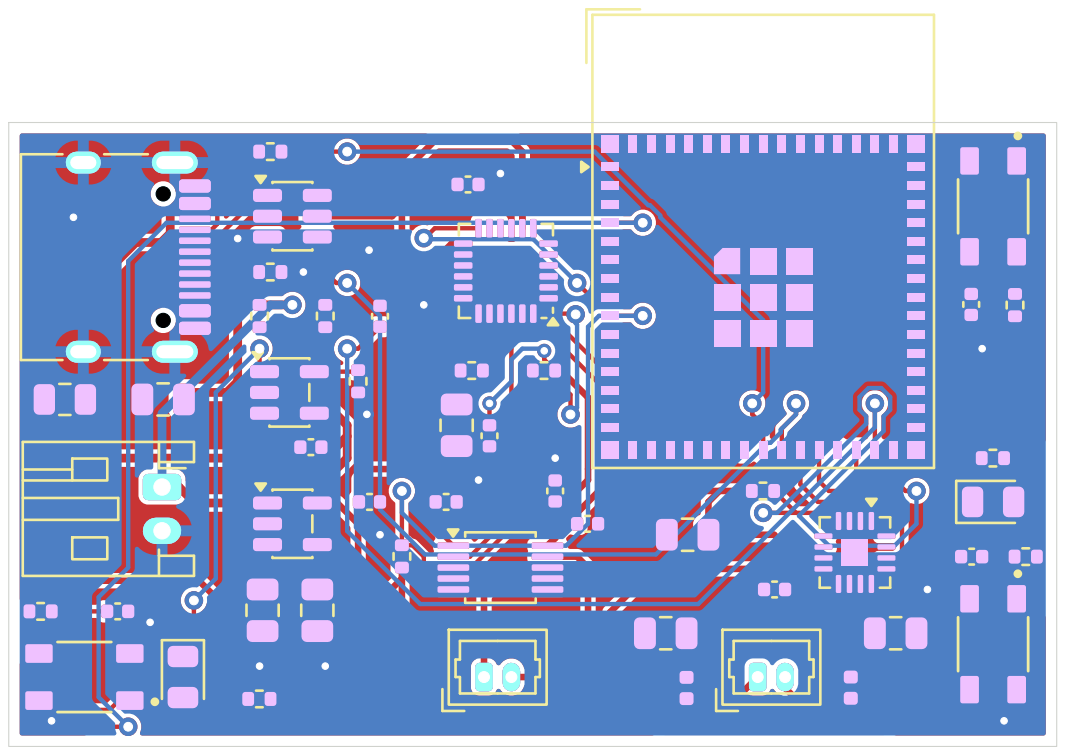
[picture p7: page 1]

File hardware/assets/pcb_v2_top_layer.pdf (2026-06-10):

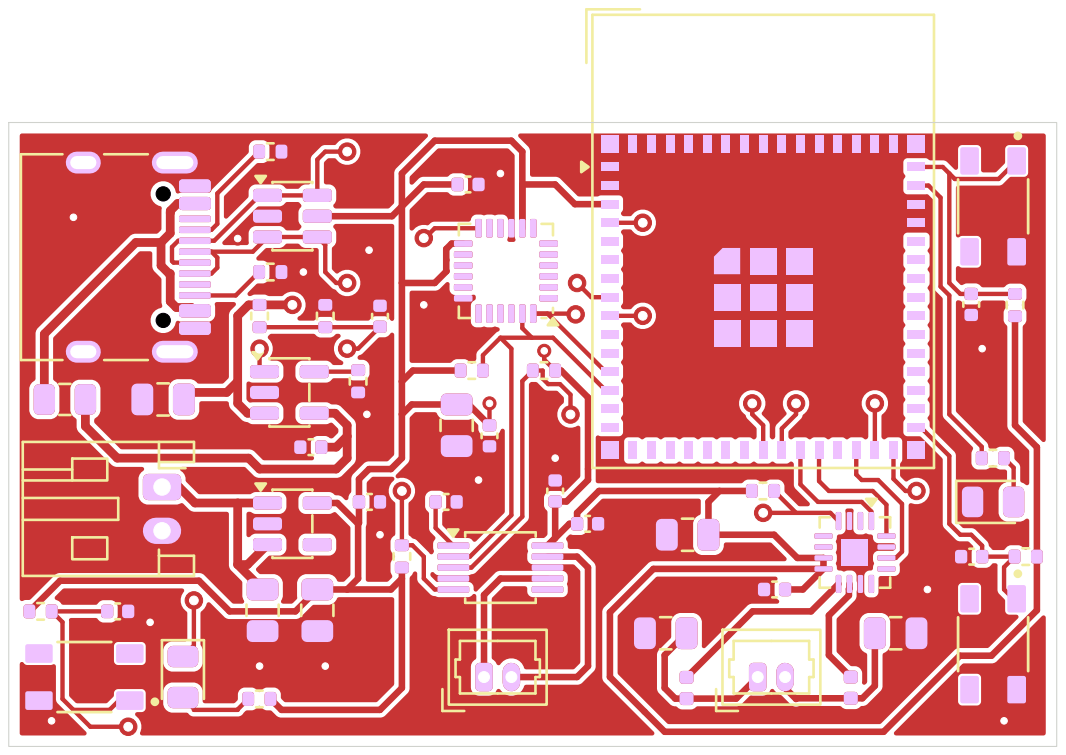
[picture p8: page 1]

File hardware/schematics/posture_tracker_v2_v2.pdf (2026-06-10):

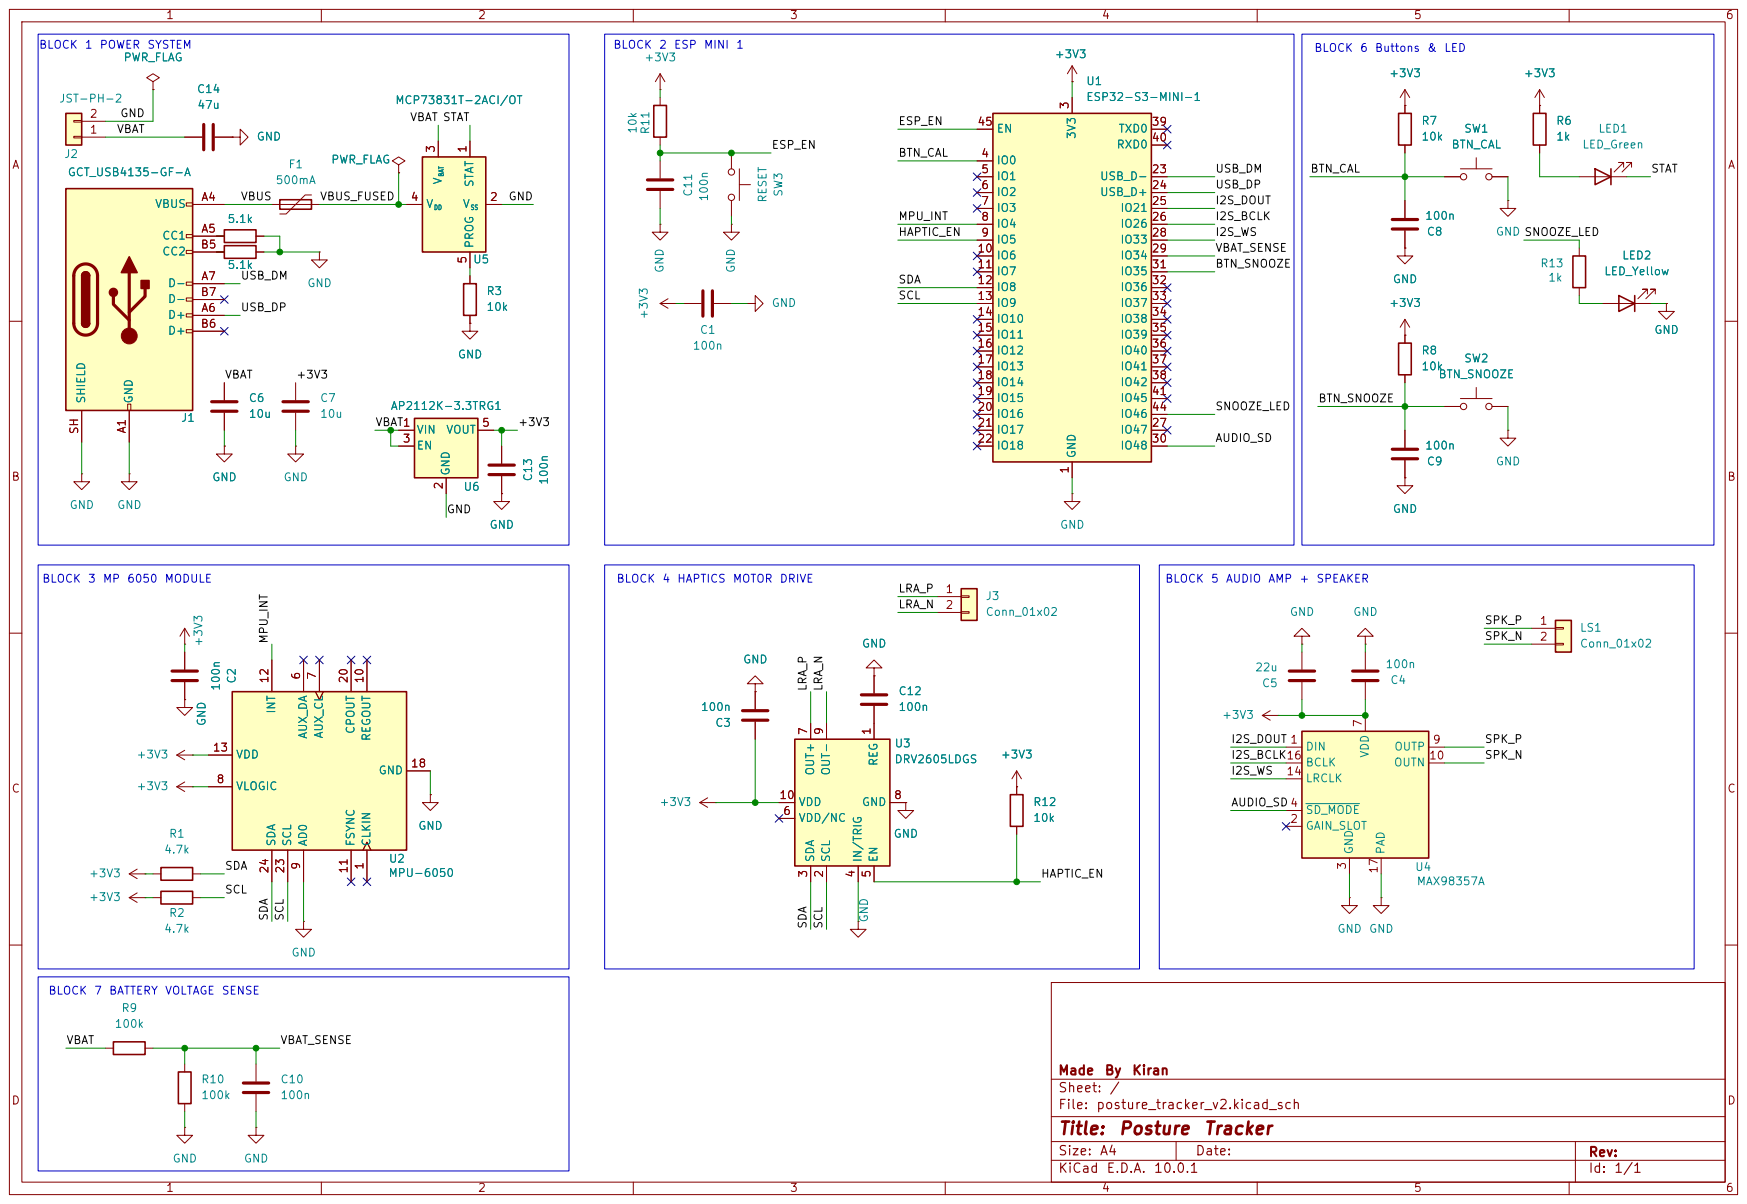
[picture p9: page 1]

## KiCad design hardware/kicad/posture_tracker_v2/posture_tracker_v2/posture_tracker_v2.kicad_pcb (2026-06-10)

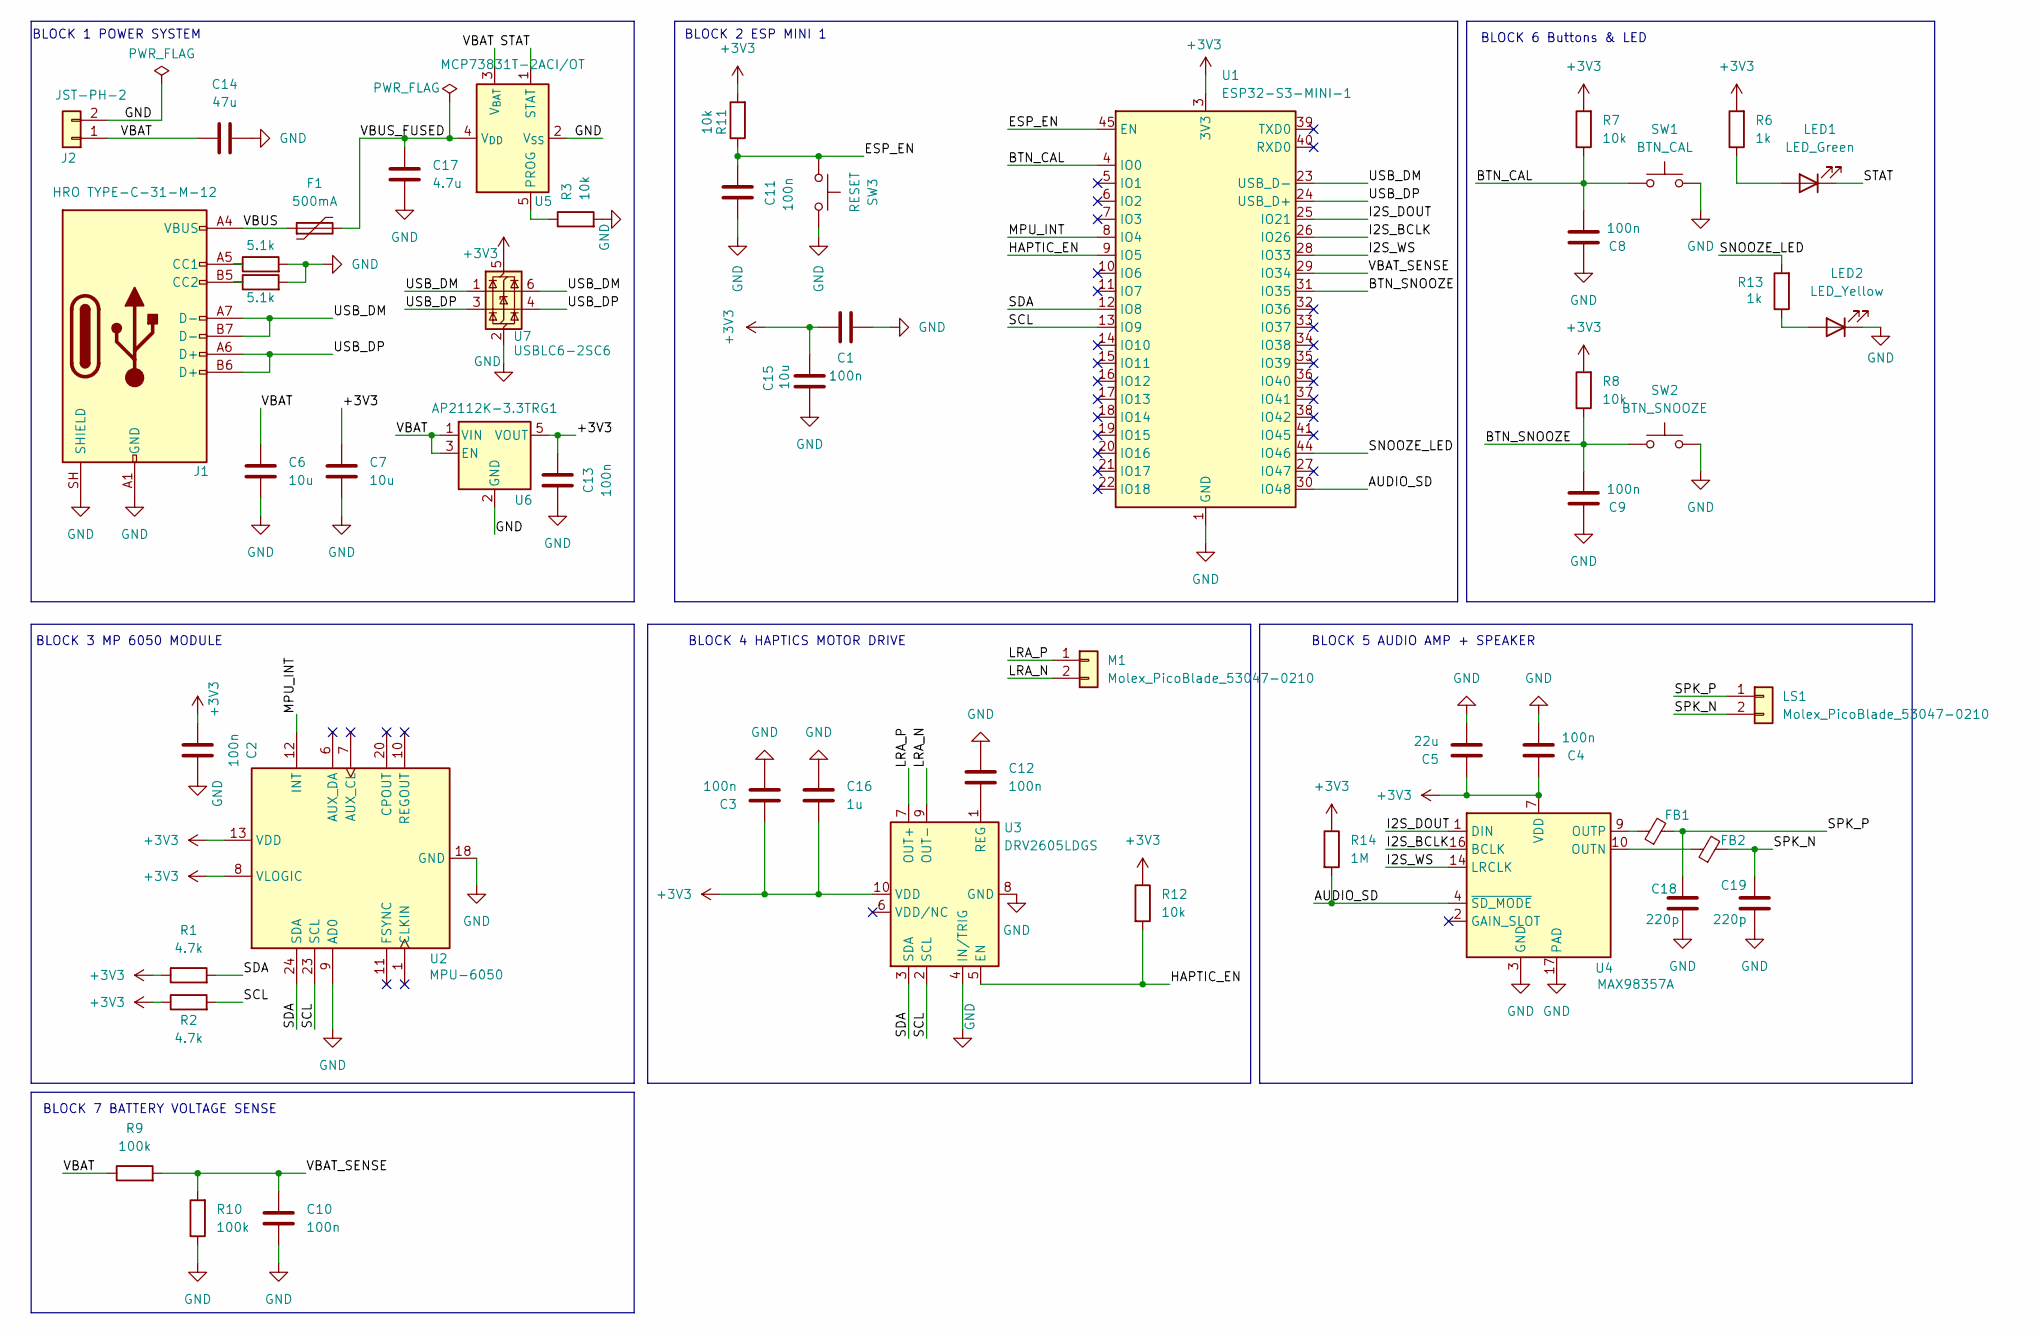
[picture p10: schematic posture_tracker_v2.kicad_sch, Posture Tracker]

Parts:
C1, C2, C3, C4, C8, C9, C10, C11, C12, C13: 100n; C_0402_1005Metric
C5: 22u; C_0805_2012Metric
C6, C7, C15: 10u; C_0805_2012Metric
C14: 47u; C_0805_2012Metric
C16: 1u; C_0402_1005Metric
C17: 4.7u; C_0402_1005Metric
C18, C19: 220p; C_0805_2012Metric
F1: 500mA; Fuse_0805_2012Metric
FB1, FB2: FerriteBead_Small; L_0402_1005Metric
J1: HRO TYPE-C-31-M-12; USB_C_Receptacle_HRO_TYPE-C-31-M-12
J2: JST-PH-2; JST_PH_S2B-PH-K_1x02_P2.00mm_Horizontal
LED1: LED_Green; LED_0805_2012Metric
LED2: LED_Yellow; LED_0805_2012Metric
LS1: Molex_PicoBlade_53047-0210; Molex_PicoBlade_53047-0210_1x02_P1.25mm_Vertical
M1: Molex_PicoBlade_53047-0210; Molex_PicoBlade_53047-0210_1x02_P1.25mm_Vertical
R1, R2: 4.7k; R_0402_1005Metric
R3, R7, R8, R11, R12: 10k; R_0402_1005Metric
R4, R5: 5.1k; R_0402_1005Metric
R6, R13: 1k; R_0402_1005Metric
R9, R10: 100k; R_0402_1005Metric
R14: 1M; R_0402_1005Metric
SW1: BTN_CAL; SW_SKRPABE010
SW2: BTN_SNOOZE; SW_SKRPABE010
SW3: RESET; SW_SKRPABE010
U1: ESP32-S3-MINI-1; ESP32-S2-MINI-1
U2: MPU-6050; InvenSense_QFN-24_4x4mm_P0.5mm
U3: DRV2605LDGS; TSSOP-10_3x3mm_P0.5mm
U4: MAX98357A; TQFN-16-1EP_3x3mm_P0.5mm_EP1.23x1.23mm
U5: MCP73831T-2ACI/OT; SOT-23-5
U6: AP2112K-3.3TRG1; SOT-23-5
U7: USBLC6-2SC6; SOT-23-6

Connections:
+3V3: C1.1, C2.1, C3.1, C4.1, C5.1, C7.1, C13.2, C15.2, C16.2, R1.1, R2.1, R6.2, R7.2, R8.2, R11.2, R12.1, R14.1, U1.3 (3V3), U2.8 (VLOGIC), U2.13 (VDD), U3.10 (VDD), U4.7 (VDD), U4.8 (VDD), U6.5 (VOUT), U7.5 (VBUS)
/AUDIO_SD: R14.2, U1.30 (IO48), U4.4 (~SD_MODE)
/BTN_CAL: C8.2, R7.1, SW1.1, U1.4 (IO0)
/BTN_SNOOZE: C9.2, R8.1, SW2.1, U1.31 (IO35)
/ESP_EN: C11.2, R11.1, SW3.1, U1.45 (EN)
/HAPTIC_EN: R12.2, U1.9 (IO5), U3.5 (EN)
/I2S_BCLK: U1.26 (IO26), U4.16 (BCLK)
/I2S_DOUT: U1.25 (IO21), U4.1 (DIN)
/I2S_WS: U1.28 (IO33), U4.14 (LRCLK)
/LRA_N: M1.2, U3.9 (OUT-)
/LRA_P: M1.1, U3.7 (OUT+)
/MPU_INT: U1.8 (IO4), U2.12 (INT)
/SCL: R2.2, U1.13 (IO9), U2.23 (SCL), U3.2 (SCL)
/SDA: R1.2, U1.12 (IO8), U2.24 (SDA), U3.3 (SDA)
/SNOOZE_LED: R13.2, U1.44 (IO46)
/SPK_N: C19.2, FB2.2, LS1.2
/SPK_P: C18.2, FB1.2, LS1.1
/STAT: LED1.1 (K), U5.1 (STAT)
/USB_DM: J1.A7 (D-), J1.B7 (D-), U1.23 (USB_D-), U7.1 (I/O1), U7.6 (I/O1)
/USB_DP: J1.A6 (D+), J1.B6 (D+), U1.24 (USB_D+), U7.3 (I/O2), U7.4 (I/O2)
/VBAT: C6.1, C14.1, J2.1, R9.1, U5.3 (V_{BAT}), U6.1 (VIN), U6.3 (EN)
/VBAT_SENSE: C10.1, R9.2, R10.2, U1.29 (IO34)
/VBUS: F1.1, J1.A4 (VBUS), J1.A9 (VBUS), J1.B4 (VBUS), J1.B9 (VBUS)
/VBUS_FUSED: C17.2, F1.2, U5.4 (V_{DD})
GND: C1.2, C2.2, C3.2, C4.2, C5.2, C6.2, C7.2, C8.1, C9.1, C10.2, C11.1, C12.2, C13.1, C14.2, C15.1, C16.1, C17.1, C18.1, C19.1, J1.A1 (GND), J1.A12 (GND), J1.B1 (GND), J1.B12 (GND), J1.SH (SHIELD), J2.2, LED2.1 (K), R3.2, R4.2, R5.2, R10.1, SW1.2, SW2.2, SW3.2, U1.1 (GND), U1.2 (GND), U1.42 (GND), U1.43 (GND), U1.46 (GND), U1.47 (GND), U1.48 (GND), U1.49 (GND), U1.50 (GND), U1.51 (GND), U1.52 (GND), U1.53 (GND), U1.54 (GND), U1.55 (GND), U1.56 (GND), U1.57 (GND), U1.58 (GND), U1.59 (GND), U1.60 (GND), U1.61 (GND), U1.62 (GND), U1.63 (GND), U1.64 (GND), U1.65 (GND), U2.9 (AD0), U2.18 (GND), U3.4 (IN/TRIG), U3.8 (GND), U4.3 (GND), U4.11 (GND), U4.15 (GND), U4.17 (PAD), U5.2 (V_{SS}), U6.2 (GND), U7.2 (GND)
unnamed: J1.A5 (CC1), R4.1
unnamed: J1.B5 (CC2), R5.1
unnamed: LED1.2 (A), R6.1
unnamed: LED2.2 (A), R13.1
unnamed: C12.1, U3.1 (REG)
unnamed: FB2.1, U4.10 (OUTN)
unnamed: FB1.1, U4.9 (OUTP)
unnamed: R3.1, U5.5 (PROG)

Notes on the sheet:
BLOCK 2 ESP MINI 1
BLOCK 4 HAPTICS MOTOR DRIVE
BLOCK 1 POWER SYSTEM
BLOCK 6 Buttons & LED
BLOCK 7 BATTERY VOLTAGE SENSE
BLOCK 3 MP 6050 MODULE
BLOCK 5 AUDIO AMP + SPEAKER

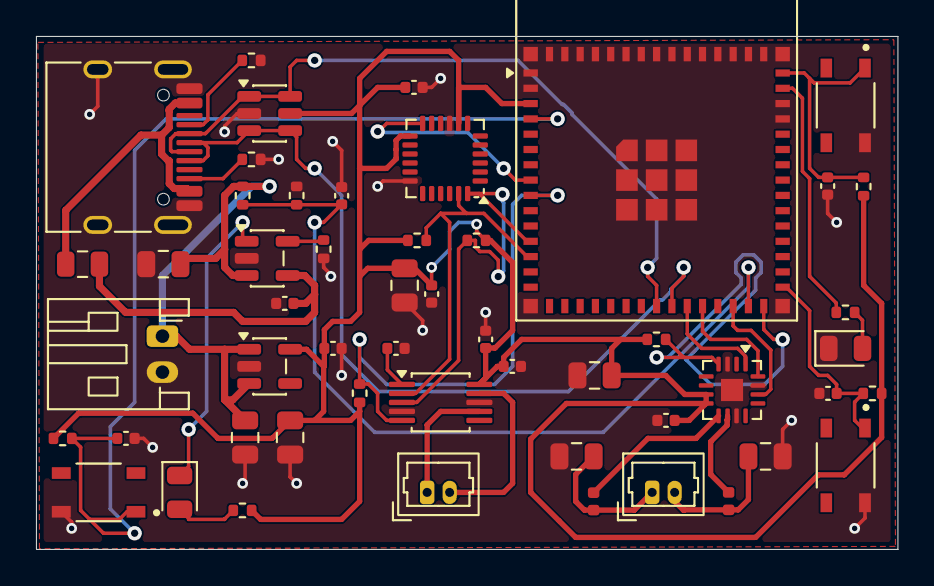
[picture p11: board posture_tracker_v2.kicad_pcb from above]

Board: 2 copper layers, 47.9 x 28.5 mm, 52 parts (0 on the bottom side), 33 nets.

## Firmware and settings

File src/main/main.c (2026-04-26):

#include "config.h"
#include <math.h>
#include "esp_log.h"
#include "esp_timer.h"
#include "freertos/FreeRTOS.h"
#include "freertos/task.h"
#include "nvs_flash.h"
#include "mpu6050.h"
#include "audio.h"
#include "posture_fsm.h"

static const char *TAG = "MAIN";

// ── Shared globals (extern'd in posture_fsm.h) ────────────────────────────
imu_data_t         g_imu_data    = {0};
SemaphoreHandle_t  g_imu_mutex   = NULL;
EventGroupHandle_t g_evt_group   = NULL;
QueueHandle_t      g_audio_queue = NULL;

// ── Task A — IMU Reader ───────────────────────────────────────────────────
static void task_read_imu(void *arg)
{
    (void)arg;
    ESP_LOGI(TAG, "IMU task started");

    uint8_t consecutive_fail = 0;
    float pitch, roll;

    for (;;) {
        esp_err_t ret = mpu6050_read_angles(&pitch, &roll);

        if (ret != ESP_OK) {
            consecutive_fail++;
            ESP_LOGW(TAG, "IMU read fail #%d", consecutive_fail);
            if (consecutive_fail >= 3) {
                ESP_LOGE(TAG, "3 consecutive IMU failures — restarting");
                esp_restart();
            }
        } else {
            consecutive_fail = 0;

            if (xSemaphoreTake(g_imu_mutex, pdMS_TO_TICKS(MUTEX_TIMEOUT_MS)) == pdTRUE) {
                g_imu_data.pitch        = pitch;
                g_imu_data.roll         = roll;
                g_imu_data.timestamp_us = esp_timer_get_time();
                xSemaphoreGive(g_imu_mutex);
                xEventGroupSetBits(g_evt_group, EVT_IMU_DATA_READY);
            } else {
                ESP_LOGW(TAG, "IMU mutex timeout — sample skipped");
            }
        }

        vTaskDelay(pdMS_TO_TICKS(IMU_SAMPLE_RATE_MS));
    }
}

// ── Calibration (synchronous, runs before tasks are created) ─────────────
static void calibrate_baseline(void)
{
    float pitch, roll;

    while (1) {
        mpu6050_reset_filter();

        audio_play_tone(400, 150, VOL_CHIME);
        vTaskDelay(pdMS_TO_TICKS(50));
        audio_play_tone(600, 150, VOL_CHIME);
        vTaskDelay(pdMS_TO_TICKS(50));
        audio_play_tone(800, 150, VOL_CHIME);
        vTaskDelay(pdMS_TO_TICKS(500));

        ESP_LOGI(TAG, "Calibration: collecting %d samples...", CAL_VALID_SAMPLES);

        float pitch_sum    = 0.0f;
        float roll_sum     = 0.0f;
        float pitch_sq_sum = 0.0f;
        float roll_sq_sum  = 0.0f;

        for (int i = 0; i < CAL_TOTAL_SAMPLES; i++) {
            mpu6050_read_angles(&pitch, &roll);
            if (i >= CAL_DISCARD_SAMPLES) {
                pitch_sum    += pitch;
                roll_sum     += roll;
                pitch_sq_sum += pitch * pitch;
                roll_sq_sum  += roll  * roll;
            }
            vTaskDelay(pdMS_TO_TICKS(IMU_SAMPLE_RATE_MS));
        }

        float n          = (float)CAL_VALID_SAMPLES;
        float pitch_mean = pitch_sum / n;
        float roll_mean  = roll_sum  / n;
        float pitch_std  = sqrtf(fabsf(pitch_sq_sum / n - pitch_mean * pitch_mean));

        ESP_LOGI(TAG, "Cal result: pitch=%.2f  roll=%.2f  pitch_stddev=%.2f",
                 pitch_mean, roll_mean, pitch_std);

        if (pitch_std > CAL_MAX_STDDEV_DEG) {
            ESP_LOGW(TAG, "Cal rejected — too much movement (pitch_stddev=%.2f > %.1f)",
                     pitch_std, CAL_MAX_STDDEV_DEG);
            audio_play_tone(600, 150, VOL_CHIME);
            vTaskDelay(pdMS_TO_TICKS(50));
            audio_play_tone(400, 200, VOL_CHIME);
            vTaskDelay(pdMS_TO_TICKS(1000));
            continue;
        }

        posture_fsm_set_baseline(pitch_mean, roll_mean);

        audio_play_tone(523, 100, VOL_CHIME);
        vTaskDelay(pdMS_TO_TICKS(30));
        audio_play_tone(659, 100, VOL_CHIME);
        vTaskDelay(pdMS_TO_TICKS(30));
        audio_play_tone(784, 150, VOL_CHIME);

        ESP_LOGI(TAG, "Calibration accepted.");
        return;
    }
}

// ── app_main ─────────────────────────────────────────────────────────────
void app_main(void)
{
    ESP_LOGI(TAG, "Posture Tracker — Phase 5 starting");

    // NVS — erase and retry if corrupted
    esp_err_t ret = nvs_flash_init();
    if (ret == ESP_ERR_NVS_NO_FREE_PAGES || ret == ESP_ERR_NVS_NEW_VERSION_FOUND) {
        nvs_flash_erase();
        ret = nvs_flash_init();
    }
    if (ret != ESP_OK) ESP_LOGW(TAG, "NVS init failed — continuing without NVS");
    else ESP_LOGI(TAG, "NVS initialised");

    ret = mpu6050_init();
    if (ret != ESP_OK) {
        ESP_LOGE(TAG, "FATAL: MPU-6050 init failed");
        abort();
    }

    ret = audio_init();
    if (ret != ESP_OK) {
        ESP_LOGE(TAG, "FATAL: audio init failed");
        abort();
    }

    // Boot tone
    audio_play_tone(500, 200, VOL_BOOT);

    // Calibration — blocks until accepted
    calibrate_baseline();

    // FreeRTOS primitives
    g_imu_mutex   = xSemaphoreCreateMutex();
    g_evt_group   = xEventGroupCreate();
    g_audio_queue = xQueueCreate(AUDIO_QUEUE_DEPTH, sizeof(audio_cmd_t));

    configASSERT(g_imu_mutex   != NULL);
    configASSERT(g_evt_group   != NULL);
    configASSERT(g_audio_queue != NULL);

    // Launch tasks
    BaseType_t r;
    r = xTaskCreatePinnedToCore(task_read_imu,    "imu",
                                TASK_STACK_IMU,   NULL,
                                TASK_PRIO_IMU,    NULL, TASK_CORE_IMU);
    configASSERT(r == pdPASS);

    r = xTaskCreatePinnedToCore(task_posture_fsm, "fsm",
                                TASK_STACK_FSM,   NULL,
                                TASK_PRIO_FSM,    NULL, TASK_CORE_FSM);
    configASSERT(r == pdPASS);

    r = xTaskCreatePinnedToCore(task_audio,       "audio",
                                TASK_STACK_AUDIO, NULL,
                                TASK_PRIO_AUDIO,  NULL, TASK_CORE_AUDIO);
    configASSERT(r == pdPASS);

    ESP_LOGI(TAG, "All tasks launched. Monitoring active.");
    // app_main returns — FreeRTOS scheduler takes over
}

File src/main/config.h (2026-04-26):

#pragma once

// ── I2C (MPU-6050) ────────────────────────────────────────────────────────
#define I2C_MASTER_PORT         I2C_NUM_0
#define I2C_MASTER_SDA_IO       21
#define I2C_MASTER_SCL_IO       22
#define I2C_MASTER_FREQ_HZ      400000      // 400kHz Fast Mode
#define I2C_TIMEOUT_MS          100

// ── MPU-6050 registers ────────────────────────────────────────────────────
#define MPU6050_ADDR            0x68
#define MPU_REG_PWR_MGMT_1      0x6B
#define MPU_REG_WHO_AM_I        0x75
#define MPU_REG_SMPLRT_DIV      0x19
#define MPU_REG_CONFIG          0x1A
#define MPU_REG_ACCEL_CONFIG    0x1C
#define MPU_REG_GYRO_CONFIG     0x1B
#define MPU_REG_ACCEL_XOUT_H    0x3B
#define MPU_WHO_AM_I_RESPONSE   0x68
#define MPU_ACCEL_SENSITIVITY   16384.0f    // LSB/g for ±2g range

// ── I2S (MAX98357A) ───────────────────────────────────────────────────────
#define I2S_PORT_NUM            I2S_NUM_0
#define I2S_BCLK_IO             26
#define I2S_WS_IO               25
#define I2S_DOUT_IO             27
#define I2S_SAMPLE_RATE_HZ      44100
#define WAV_SAMPLE_RATE_HZ      16000       // sit_up.wav recorded at 16kHz
#define I2S_BITS_PER_SAMPLE     16
#define I2S_DMA_BUF_COUNT       8
#define I2S_DMA_BUF_LEN_SMPLS  512

// ── IMU sampling ─────────────────────────────────────────────────────────
#define IMU_SAMPLE_RATE_MS      100         // Task A loop delay (ms)
#define LPF_ALPHA               0.15f       // EMA coefficient — lower = smoother

// ── Calibration ───────────────────────────────────────────────────────────
#define CAL_TOTAL_SAMPLES       30          // 3 seconds at 100ms per sample
#define CAL_DISCARD_SAMPLES     5           // Discard first 500ms (filter settle)
#define CAL_MAX_STDDEV_DEG      5.0f        // Reject cal if stddev exceeds this
#define CAL_VALID_SAMPLES       (CAL_TOTAL_SAMPLES - CAL_DISCARD_SAMPLES)

// ── Posture thresholds ────────────────────────────────────────────────────
#define WARN_THRESH_DEG         10.0f       // ° from baseline → WARNING state
#define BAD_THRESH_DEG          20.0f       // ° from baseline → BAD state
#define JUMP_FILTER_DEG         60.0f       // ° — discard violent movement sample

// ── State machine timings ─────────────────────────────────────────────────
#define WARN_GRACE_MS           3000        // ms above WARN_THRESH before alert fires
#define BAD_GRACE_MS            5000        // ms above BAD_THRESH before BAD fires
#define RESET_COOLDOWN_MS       2000        // ms in RESET before returning to GOOD
#define REPEAT_ALERT_MS         8000        // ms between repeated BAD alerts
#define ESCALATION_CAP          3           // beep cycles before switching to voice clip
#define GOOD_STREAK_REWARD_MS   30000       // ms of GOOD before reward chime (30s)

// ── Audio volumes (0.0 – 1.0) ─────────────────────────────────────────────
#define VOL_WARNING             0.35f
#define VOL_BAD                 0.80f
#define VOL_CHIME               0.55f
#define VOL_VOICE               0.90f
#define VOL_BOOT                0.50f
#define TONE_FADE_MS            10          // Fade in/out ms — prevents speaker click

// ── FreeRTOS ─────────────────────────────────────────────────────────────
#define AUDIO_QUEUE_DEPTH       5
#define TASK_STACK_IMU          4096
#define TASK_STACK_FSM          4096
#define TASK_STACK_AUDIO        8192
#define TASK_PRIO_IMU           5
#define TASK_PRIO_FSM           4
#define TASK_PRIO_AUDIO         3
#define TASK_CORE_IMU           0
#define TASK_CORE_FSM           0
#define TASK_CORE_AUDIO         1
#define MUTEX_TIMEOUT_MS        5           // Max ms to wait for imu_mutex before skip

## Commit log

2026-04-26 phase0: toolchain verification, project scaffold, build + flash verified
    - Add platformio.ini, root CMakeLists.txt, sdkconfig.defaults
    - Add full src/main scaffold: config.h, main.c, mpu6050, audio, posture_fsm stubs
    - Add placeholder voice/sit_up.wav for embed_files compilation
    - Fix flash size: board_build.flash_size=4MB + CONFIG_ESPTOOLPY_FLASHSIZE_4MB=y
    - Fix partition table overlap: CONFIG_PARTITION_TABLE_OFFSET=0x9000
    (ESP-IDF 5.5 bootloader ~29KB overruns default 0x8000 offset)
    - Add .gitignore excluding .pio/ build artifacts
    - Update CLAUDE.md: platformio.ini, sdkconfig workflow, file structure, Phase 0 entry
    - Update PHASES.md: Phase 0 section with full pass criteria, issues found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
    [config.h, main.c, mpu6050.c]
2026-04-26 phase1: I2C driver + raw IMU data verified on hardware
    - Implement mpu6050_write_reg() — single register write via ESP-IDF legacy I2C
    - Implement mpu6050_read_regs() — burst read with repeated-start sequence
    - Implement mpu6050_init() — I2C install, sensor wake, 100ms settle, WHO_AM_I
    verify (0x68), sample rate 100Hz, DLPF ~21Hz, accel ±2g, gyro ±250deg/s
    - Implement mpu6050_read_raw() — 6-byte burst read, reconstruct ax/ay/az int16
    - Update main.c — init + 100ms print loop, abort on init failure
    - Update mpu6050.h — declare read_raw, keep reset_filter stub for Phase 2
    - Update README.md — confirmed sensor axis map from real hardware session:
    ax+ left ax- right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
    [main.c, mpu6050.c]
2026-04-26 Phase 2: angle computation + low-pass filter
    Replace mpu6050_read_raw with mpu6050_read_angles — scales raw int16
    to g units, computes pitch/roll via atan2f, applies EMA filter (alpha=0.15).
    main.c updated to print degrees. README updated with verified axis map
    and angle ranges from real hardware testing.
    Verified on hardware 2026-04-25:
    pitch large + → tilt left, pitch large - → tilt right
    roll large + → nose up, roll large - → nose down
    At-rest noise < ±0.3°, filter convergence ~1–1.5s
    [main.c, mpu6050.c]
2026-04-26 Phase 3: I2S driver + speaker output
    Implement audio_init() with legacy I2S master TX driver (driver/i2s.h),
    audio_play_tone() with sine wave generation and 10ms fade envelope,
    audio_play_sequence() for multi-tone patterns, and all tone sequence
    definitions. task_audio() and audio_play_wav() stubbed for Phase 5.
    main.c updated to call audio_init() at boot and play a 500Hz/200ms
    boot tone before entering the IMU loop. Added sdkconfig entry to
    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
2026-04-26 Phase 4: calibration system
    Implement calibrate_baseline() — plays prompt tones, collects 30 samples
    at 100ms (3 seconds), discards first 5 (filter warmup), computes pitch/roll
    mean and pitch stddev. Rejects calibration if pitch_stddev > 5°, plays fail
    tone, and retries automatically. On acceptance, locks baseline via
    posture_fsm_set_baseline() and plays success arpeggio.
    Validates on pitch stddev only — roll = atan2(gy, gz) is unstable when
    sensor is vertical (gz≈0, e.g. mounted on human back), producing ~11° noise
    stddev even when perfectly still. Pitch has no such singularity.
    Fixed CAL_TOTAL_SAMPLES from 300→30 and CAL_DISCARD_SAMPLES from 50→5
    to match the intended 3-secon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
    [config.h, main.c]
2026-04-26 Phase 5: FreeRTOS tasks + state machine + full audio integration
    Three concurrent tasks: IMU reader (Core 0, prio 5), posture FSM (Core 0,
    prio 4), audio player (Core 1, prio 3). Shared state via mutex + event group
    + queue per CLAUDE.md architecture.
    Posture FSM: GOOD → WARNING (10°, 3s grace) → BAD (20°, 5s grace) → RESET
    (2s cooldown). Escalation in BAD: 3 double beeps at 8s intervals, then
    voice clip repeating every 8s until posture corrected.
    Voice clip fix: i2s_set_clk() switches to 16kHz for WAV playback, back to
    44.1kHz for tones — prevents chipmunk-speed playback.
    WAV embedded as C array (sit_up_wav.c) — EMBED_FILES not honored by
    PlatformIO ESP-IDF build system.
    Tim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
    [config.h, main.c]
2026-04-26 V2: add CLAUDE_V2.md and README_V2.md — full product architecture
2026-04-26 V2: add PHASES_V2.md — full phase build guide for phases 7-11
2026-04-26 V2: document hardware procurement — components confirmed and ordered
    - PHASES_V2.md: add full hardware procurement log with order refs,
    component selection rationale, confirmed specs, and Phase 10 BOM
    (not yet ordered — pending Phase 7-9 validation)
    - README_V2.md: update phase table with hardware status column
    - CLAUDE_V2.md: update BOM and LRA section with confirmed parts
    (Vybronics VG1030001XH, MECCANIXITY 20mm speaker, Adafruit #2750 LiPo)
2026-04-26 V2: add hardware folder structure — datasheets, schematics, pcb, enclosure, bom
    - hardware/datasheets/ — placeholder + download checklist for all 9 component datasheets
    - hardware/schematics/ — placeholder, blocked until Phase 7-9 validated
    - hardware/pcb/ — placeholder with target specs (45x35mm, 2-layer, ENIG, JLCPCB)
    - hardware/enclosure/ — placeholder with clip design requirements
    - hardware/bom/ — master BOM with confirmed parts and order status
2026-04-26 V2: update BOM with LiPo charger breakout, update datasheet status
2026-04-26 V2: remove Elegoo sensor kit folder from datasheets — not relevant to V2
2026-04-27 V2: add KiCad project structure, beginner guide, and context file
    [Untitled.kicad_pcb, Untitled.kicad_sch]
2026-04-27 V2: remove auto-created Untitled KiCad project, add .gitignore for KiCad artifacts
    KiCad created an "Untitled" project on first launch with lock files,
    .history submodule, and backup zips. Remove these from tracking.
    Add .gitignore to exclude KiCad's auto-generated noise going forward.
    The real project should be saved as posture_tracker_v2 per KICAD_BEGINNER_GUIDE.md.
    [Untitled.kicad_pcb, Untitled.kicad_sch]
2026-04-27 V2: update KiCad context — Block 1 power schematic complete
2026-04-27 V2: update README files to reflect KiCad progress — Block 1 schematic complete
2026-05-02 V2: fix I2C GPIO assignment — GPIO22 does not exist on ESP32-S3
    SDA reassigned from GPIO21 to GPIO8
    SCL reassigned from GPIO22 to GPIO9
    GPIO22-25 do not exist on ESP32-S3 (only on original ESP32)
2026-05-02 V2: add SCHEMATIC_GUIDE.md — full reasoning for every block and component
2026-05-02 V2: add SPICE simulation results to schematic guide
    EN reset delay and I2C pull-up rise time both verified — design correct.
2026-05-02 V2: add KiCad project files — Blocks 1-3 schematic, correct ESP32-S3-MINI-1U footprint
    - Block 1 (Power): J1, F1, U5, U6, J2 complete, ERC clean
    - Block 2 (MCU): ESP32-S3-MINI-1U with correct PCM_Espressif footprint
    - Block 3 (IMU): MPU-6050 with I2C pull-ups
    - Fixed footprint from RF_Module:ESP32-S2-MINI-1 to PCM_Espressif:ESP32-S3-MINI-1U
    [posture_tracker_v2.kicad_pcb, posture_tracker_v2.kicad_sch]
2026-05-03 V2: apply Reddit review fixes — USB-C wiring, decoupling caps, footprint correction
    - Fix USB-C B6/B7 cross-connection: A6+B7=D+, A7+B6=D- per USB-IF spec
    (diagonal pairing so both cable orientations work — previously B6/B7 had no net)
    - Add C17 (4.7µF, 0402) on VBUS_FUSED for MCP73831 VDD decoupling
    - Add C15 (10µF, 0805) bulk cap on ESP32-S3 VDD33 rail
    - Add C16 (1µF, 0402) local bulk cap on DRV2605L VDD
    - Fix U1 footprint: ESP32-S2-MINI-1 (52 pads) → ESP32-S3-MINI-1 (65 pads)
    - Delete premature Gerbers (exported before routing — regenerate after routing)
    - ERC clean: 0 errors, 5 warnings (all cosmetic/acceptable)
    - DRC: 4 cosmetic silkscreen warnings, 148 unconnected pads (ro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
    [posture_tracker_v2.kicad_pcb, posture_tracker_v2.kicad_sch]
2026-05-04 WIP: PCB layout routing setup — clean DRC baseline, connector updates
    - PCB: cleared all routing, established clean DRC baseline (154 unconnected,
    2 acceptable silk warnings for U1 antenna overhang, 0 copper errors)
    - PCB: GND routing strategy decided — B.Cu copper pour filled at end,
    no manual GND traces; Power/Default net classes configured
    - Schematic: J3 (LRA) and LS1 (speaker) connector footprints set to
    JST GH 1.25mm vertical to match physical cable connectors on
    Vybronics LRA and MECCANIXITY 20mm speaker
    - .gitignore: added DS_Store, KiCad lock/backup/temp files, KiCad plot PDFs
    - README_V2.md: updated Phase 10 status, added PCB layout state section
    - hardware/pcb/README.m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
    [posture_tracker_v2.kicad_pcb, posture_tracker_v2.kicad_sch]
2026-05-04 docs: consolidate to single doc set, remove V1 legacy files
    Remove the three V1 breadboard docs carried forward from main branch
    (README.md, CLAUDE.md, PHASES.md) and rename V2 equivalents to standard
    names so the branch has a single authoritative doc set.
    Changes:
    - README_V2.md → README.md (V2 is now the default landing page)
    - CLAUDE_V2.md → CLAUDE.md (V2 is now the AI context)
    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
2026-05-04 Phase 8: replace voice clips with macOS Samantha TTS, fix end click
    Regenerated sit_up.wav and thank_you_good_work.wav using macOS `say`
    (Samantha voice, -r 155 WPM) + afconvert to 16kHz 16-bit mono. Previous
    clips were flat TTS that sounded monotone and low-pitched on the 20mm 8Ω
    speaker. New recordings are clearer and more natural on the small cone.
    Added 200ms silence padding to sit_up.wav to eliminate the click caused
    by i2s_set_clk restoring 44.1kHz before the DMA buffer drains fully.
    Added gen_wav_arrays.py to regenerate .c arrays from WAV files without
    manual xxd — run from repo root after updating any WAV file.
    Phase 8 pass criteria verified on hardware:
    - Boot tone, cal tones,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
2026-06-05 chore: gitignore KiCad auto-generated files, untrack reports and backups
    Add patterns for *.wbk, DRC/ERC reports, layer PDFs, gerber outputs,
    and .DS_Store. Untrack DRC.rpt, ERC.rpt, report.txt, and *.wbk that
    were previously committed — these regenerate on every KiCad run.
2026-06-05 V2: update KiCad schematic — Block 4 routing and component updates
    [posture_tracker_v2.kicad_sch]
2026-06-05 audio: re-encode voice WAV files — reduce file size
    sit_up.wav: 46KB → 38KB, thank_you_good_work.wav: 58KB → 53KB.
    Regenerate corresponding _wav.c arrays.
2026-06-05 V2: clear all PCB traces — restart routing from scratch
    Removed all 127 routed segments. Footprints, copper zones, board
    outline, and net assignments are preserved. Ratsnest is now the
    full unrouted state.
    [posture_tracker_v2.kicad_pcb]
2026-06-05 V2: update speaker and motor connectors to Molex PicoBlade 53047-0210
    LS1 (speaker): JST GH 1.25mm → Molex PicoBlade 53047-0210
    GH was wrong — wire too thick to crimp, fiddly for hand assembly.
    PicoBlade is 1.25mm pitch, low-profile, looks clean in 3D render,
    correct gauge for thin speaker wire leads.
    J3 → M1 (LRA motor): 2.54mm pin header → Molex PicoBlade 53047-0210
    Renamed J3 to M1 to match BOM/CLAUDE.md reference. Same connector
    as LS1 for consistency — motor wire leads same gauge as speaker.
    Both use: Connector_Molex:Molex_PicoBlade_53047-0210_1x02-1MP_P1.25mm_Vertical
    [posture_tracker_v2.kicad_sch]
2026-06-05 V2: add Molex PicoBlade 53398-0271 3D model for LS1 and M1 footprints
    STEP file for the 2-pin vertical PicoBlade connector used for both
    the speaker (LS1) and LRA motor (M1). Stored in project so the 3D
    model path doesn't break when the project moves machines.
    Path to assign in KiCad footprint properties:
    ${KIPRJMOD}/../3dmodels/Connector_Molex.3dshapes/Molex_PicoBlade_53398-0271_1x02-1MP_P1.25mm_Vertical.step
2026-06-05 V2: update PCB footprints and 3D models for LS1 and M1
    LS1 and M1 footprints updated in PCB from old connectors to
    Molex PicoBlade 53047-0210 (1x02, 1.25mm vertical).
    3D model assigned: Molex_PicoBlade_53398-0271_1x02-1MP_P1.25mm_Vertical.step
    Schematic 4-char value fix included.
    [posture_tracker_v2.kicad_pcb, posture_tracker_v2.kicad_sch]
2026-06-08 V2: switch LS1 and M1 to Molex PicoBlade horizontal variant (53261-0271)
    Horizontal connector has wire exiting parallel to PCB — lower profile
    for a wearable, easier cable routing out the side of the enclosure.
    Footprint: Molex_PicoBlade_53261-0271_1x02-1MP_P1.25mm_Horizontal
    3D model: Molex_PicoBlade_53261-0271_1x02-1MP_P1.25mm_Horizontal.step
    Remove vertical 3D model (53398-0271) — no longer needed.
    Run "Update PCB from Schematic" in KiCad to apply new footprint,
    then reassign 3D model using:
    ${KIPRJMOD}/../3dmodels/Connector_Molex.3dshapes/Molex_PicoBlade_53261-0271_1x02-1MP_P1.25mm_Horizontal.step
2026-06-08 V2: clear all PCB traces — restart routing from scratch
    Removed all 7 remaining routed segments. 57 footprints and 13 copper
    zones intact. FB1 (ferrite bead) confirmed clean — L_0402_1005Metric
    footprint with 0.38mm pad clearance, DRC violation was from a prior
    stale placement now resolved.
    Board is now a clean ratsnest ready for routing.
    [posture_tracker_v2.kicad_pcb, posture_tracker_v2.kicad_sch]
2026-06-10 V2: PCB routing complete — DRC clean, Gerbers ready for JLCPCB
    - All nets fully routed on F.Cu; HAPTIC_EN and MPU_INT via B.Cu
    - Trace widths corrected per IPC-2221: VBUS/VBUS_FUSED 0.4mm,
    +3V3/VBAT/audio/motor 0.3mm, signals 0.2mm
    - Net classes written to .kicad_pro (HighCurrent, Power, Audio, Motor,
    USB_Diff, Default) with 0.8mm/0.4mm vias across all 19 vias
    - F.Cu + B.Cu GND copper fills with solid pad connection + stitching vias
    - Final DRC: 0 errors, 0 unconnected, 2 cosmetic silk warnings only
    - Gerbers exported to hardware/pcb/v2/gerbers/ (10 layers + 2 drill files)
    - ZIP ready: hardware/pcb/v2/posture_tracker_v2_gerbers.zip
    - Hardware folder structure reorganised: KiCad source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
    [posture_tracker_v2-B_Cu.gbl, posture_tracker_v2-B_Mask.gbs, posture_tracker_v2-B_Paste.gbp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]
2026-06-10 docs: consolidate _V2 docs into primary files, delete duplicates
    Merged all unique V2 content (Phase 10 status, checklists, hardware
    visuals, IPC-2221 trace widths) into README.md and PHASES.md.
    Deleted CLAUDE_V2.md, PHASES_V2.md, README_V2.md — one canonical doc
    per topic on the release/v2-product branch.
2026-06-10 docs: add color PCB layer PDFs exported via kicad-cli
    Three vector PDFs generated from KiCad source (color, autoscale, white
    background): top layer, bottom layer (mirrored), and combined. README
    updated to link PDFs in Hardware Visuals section.
2026-06-10 docs: replace PDF table with PCB layer screenshots in README
    Three manual KiCad screenshots added (top, bottom, combined layers).
    PDF links kept as secondary references below the schematic section.
    Fixed typo in bottom layer filename (cb_ → pcb_).
2026-06-10 docs: remove old unused PCB PNGs (pcb_v2_top, schematic_v2)
    Replaced by pcb_v2_top_layer.png, pcb_v2_bottom_layer.png, pcb_v2_combined.png.
    Schematic now referenced via PDF only.
2026-06-10 docs: restore schematic screenshot in README
    Re-added schematic_v2.png to hardware/assets and README visuals section.
2026-06-10 docs: replace static 3D PNG with animated GIF of KiCad 3D viewer
